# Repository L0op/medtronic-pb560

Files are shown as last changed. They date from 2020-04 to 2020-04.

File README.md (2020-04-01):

# medtronic-pb560
Medtronic PB560 Ventilator System design files. Medtronic distributes these files [here](http://www.medtronic.com/openventilator). The use and distribution of these files is subject to the terms of the license in [permissive-license-open-ventilator.pdf](permissive-license-open-ventilator) ([license on Medtronic's website](https://www.medtronic.com/content/dam/medtronic-com/global/Corporate/covid19/documents/permissive-license-open-ventilator.pdf)). **This license is *not* an [Open-source/Open-hardware license](https://en.wikipedia.org/wiki/Open-source_hardware) in any normal sense.** Specifically:

> _Limited Term._ This permissive license is effective from the time you download the Design Materials and Software until the earlier of (i) the final day the WHO’s PHEIC is in effector  (ii) October 1, 2024 (the “Term”).

Elsewhere:

> **COVID-19 Warning: This Ventilator was created for use onlyin response to the COVID-19 pandemic.  It is provided AS IS.**

The distribution of these materials is solely for the purpose of producing my ventilator.

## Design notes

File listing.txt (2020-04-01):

"."
├── "file-set-1"
│   ├── "Electrical Schematics"
│   │   ├── "10039639C00_Power Supply Board - Tantalum Less_SCH.pdf"
│   │   ├── "10105965B00_10106052_POWERPACK2 BOARD (DUAL BATTERY).pdf"
│   │   ├── "4096600.E00.001_Schma Carte Commande Turbine RB0505 IND03.pdf"
│   │   ├── "4096600.E01.001_Schma Carte Connexion Batterie IND02.pdf"
│   │   ├── "4096600E03001_CPU BOARD SCH.pdf"
│   │   └── "4096600E04001_BUZZER BOARD SCH.pdf"
│   ├── "Manuals"
│   │   ├── "Manual - Service - PB560 - English .pdf"
│   │   └── "Manual - User PB560 - English.pdf"
│   ├── "Manufacturing Documents"
│   │   ├── "PB560 - Quality Process Flow - Manufacturing Procedures"
│   │   │   ├── "10036007Z00_PB560 SYSTEM CALIBRATION AND TEST PROCEDURE.pdf"
│   │   │   ├── "10037308AJ00.pdf"
│   │   │   ├── "10039030M00_PB560 SYSTEM FINAL TEST PROCEDURE.pdf"
│   │   │   ├── "10039897AH00_PB560 PACK.pdf"
│   │   │   ├── "10076002D00_PB500 ELECTRICAL SAFETY TEST AND BUZZER CARD CHARGE PROCEDURE.pdf"
│   │   │   ├── "10095161P00_PB560 ASSEMBLY PROCEDURE 1.pdf"
│   │   │   ├── "10095162H00_PB560 ASSEMBLY PROCEDURE 2.pdf"
│   │   │   └── "10095163H00_PB560 ASSEMBLY PROCEDURE 3.pdf"
│   │   └── "PB560 Power Pack - Quality Process Flow - Manufacturing Procedures"
│   │       ├── "10071204L00 - PB500 Series Power Pack Quality Process Flow.pdf"
│   │       ├── "10099745H00 - PB500 Power Pack Assembly & Test procedure.pdf"
│   │       ├── "10124919G00 - PB500 series Power Pack2 DHR.pdf"
│   │       ├── "10128152J00 - PB500 series POWERPACK 2 pack procedure.pdf"
│   │       └── "10140875D00 - PB500 Powerpack FRU DHR.pdf"
│   ├── "Requirements Documents"
│   │   ├── "10035480AM00 - Product Requirements Document.pdf"
│   │   ├── "10037185AB0 - Software Requirements Specification Document.pdf"
│   │   └── "10053865Q00 - PB560 Ventilator & Power Pack Essential Requirements Matrix.pdf"
│   └── "Permissive License--Open Ventilator.pdf"
├── "file-set-2"
│   ├── "3D CAD Models"
│   │   ├── "039281023.SLDPRT"
│   │   ├── "09-48-4038.SLDPRT"
│   │   ├── "09-48-4128.SLDPRT"
│   │   ├── "10000916.SLDPRT"
│   │   ├── "10049560_Fan Assy (ref ASM).SLDASM"
│   │   ├── "10049560_Routed wires (asm ref Part).SLDPRT"
│   │   ├── "10049560_ventil SUNON 40x40x20.SLDPRT"
│   │   ├── "10079556.SLDASM"
│   │   ├── "10079556_Support.SLDPRT"
│   │   ├── "10083602.SLDPRT"
│   │   ├── "10093284.SLDPRT"
│   │   ├── "10096315.SLDASM"
│   │   ├── "10096505_Board (ref ECAD).SLDPRT"
│   │   ├── "10096509.SLDASM"
│   │   ├── "10096510.sldasm"
│   │   ├── "10096510_Bare Board.SLDPRT"
│   │   ├── "10096511.SLDASM"
│   │   ├── "10096512.SLDASM"
│   │   ├── "10100017.SLDPRT"
│   │   ├── "10100018.SLDPRT"
│   │   ├── "1mm bumper.SLDPRT"
│   │   ├── "2004200 Rondelle plate - MN INOX 3 x 8 EP 0.8.sldprt"
│   │   ├── "22-05-7028.SLDPRT"
│   │   ├── "22-27-2021.SLDPRT"
│   │   ├── "26-48-1035.SLDPRT"
│   │   ├── "26-48-1125.SLDPRT"
│   │   ├── "2961500 Pieds autocollants 12.7x12.7 ep5.8.SLDPRT"
│   │   ├── "2963500 batterie legendair.SLDPRT"
│   │   ├── "2966300 (ref AML).SLDPRT"
│   │   ├── "2970100 goupille cylindrique DIA 2x28.SLDPRT"
│   │   ├── "2970300 raccord droit 2.4x3.2 plastique.SLDPRT"
│   │   ├── "2970400 Raccord TE 2.4 plastique.SLDPRT"
│   │   ├── "2970900 vanne  A-M O2 FAS.SLDPRT"
│   │   ├── "2970999 Vanne  A-M O2 FAS.SLDASM"
│   │   ├── "2973900 (ref AML).SLDPRT"
│   │   ├── "2980100 ferrite 18.8x28.5x13.2.SLDPRT"
│   │   ├── "3808400.SLDASM"
│   │   ├── "3808400_plastic only.SLDPRT"
│   │   ├── "3808801 support cone expiration legendair.SLDPRT"
│   │   ├── "3810200.SLDPRT"
│   │   ├── "3812400 entretoise hexa M-F M3.SLDPRT"
│   │   ├── "3812500 tole blindage toron moteur.SLDPRT"
│   │   ├── "3814200.SLDPRT"
│   │   ├── "3814400 ressort capot.SLDPRT"
│   │   ├── "3822000.SLDPRT"
│   │   ├── "3822500.SLDASM"
│   │   ├── "3822500_WIRES.SLDPRT"
│   │   ├── "3823200.sldasm"
│   │   ├── "3824300 Assy with labels (ref Assy).SLDASM"
│   │   ├── "3824300_Main block.SLDPRT"
│   │   ├── "3824300_Plastic Insert.SLDPRT"
│   │   ├── "3825500.SLDPRT"
│   │   ├── "3827900.SLDPRT"
│   │   ├── "3828200 etiq ident caisson turbine.SLDPRT"
│   │   ├── "3828200.SLDPRT"
│   │   ├── "3828299 REF ASSY (INCLUDES FOAM).SLDASM"
│   │   ├── "3838600 etiq ID+code barre revB.SLDPRT"
│   │   ├── "3838600.SLDPRT"
│   │   ├── "3845900_cable.SLDPRT"
│   │   ├── "3845900_ferrite tube plat 1,3x6,5 prof10 larg 40.SLDPRT"
│   │   ├── "3846100.SLDASM"
│   │   ├── "3846100_Cable.SLDPRT"
│   │   ├── "39-26-7265.SLDPRT"
│   │   ├── "39-28-5104.SLDPRT"
│   │   ├── "39-28-5264.SLDPRT"
│   │   ├── "3M 4032 x30mm.SLDPRT"
│   │   ├── "3M 7810-0000PR.SLDPRT"
│   │   ├── "4096600 (PB560) 2017.SLDASM"
│   │   ├── "4096600.M00.023 boitier capteur debit.SLDPRT"
│   │   ├── "43650-0224.SLDPRT"
│   │   ├── "60601-1 Test Finger.SLDPRT"
│   │   ├── "702-09 Entretoise AV Legendair.SLDPRT"
│   │   ├── "90151-2110.SLDPRT"
│   │   ├── "901700010 avec patte.SLDPRT"
│   │   ├── "90635-1102 +90170-0010 molex avec patte.SLDASM"
│   │   ├── "90635-1102.SLDPRT"
│   │   ├── "AFFICHEUR TWIN.SLDPRT"
│   │   ├── "Back End Cap.SLDPRT"
│   │   ├── "Batt Assy.SLDASM"
│   │   ├── "Batt Contacts tab.SLDPRT"
│   │   ├── "Batt PCB Assy.SLDASM"
│   │   ├── "Batt PCB.SLDPRT"
│   │   ├── "Cable tie (ref AML).SLDPRT"
│   │   ├── "Coude banjo M5-tuyau 6.SLDPRT"
│   │   ├── "Exh Valve connector.SLDPRT"
│   │   ├── "Extruded housing.SLDPRT"
│   │   ├── "Front End Cap.SLDPRT"
│   │   ├── "HARTING 09185107323.SLDPRT"
│   │   ├── "HIROSE HR25A-7R-8S.SLDPRT"
│   │   ├── "HIROSE HR30-6R-6S.SLDPRT"
│   │   ├── "I0 178 Entretoise AR Legendair.SLDPRT"
│   │   ├── "I0 179 Entretoise Mediane Legendair.SLDPRT"
│   │   ├── "INGUN GKS 913 305 230 A 15 02 S.SLDPRT"
│   │   ├── "Insp Mod Connector.SLDPRT"
│   │   ├── "List of 3D CAD files.txt"
│   │   ├── "MODULE PRISE 230+INTER.SLDPRT"
│   │   ├── "MOLEX 22-05-7088.SLDPRT"
│   │   ├── "MOLEX 22-05-7098.SLDPRT"
│   │   ├── "MOLEX 43645 0200.SLDPRT"
│   │   ├── "MOLEX 43650-0212.SLDPRT"
│   │   ├── "Molex 90635-1262.SLDPRT"
│   │   ├── "PMCD1204.sldasm"
│   │   ├── "PRECI-DIP 811-S1-002-30-014101.SLDPRT"
│   │   ├── "Rondelle plate - ZU  3 x 6 EP 0.8.sldprt"
│   │   ├── "Vis KA22x5 hexalobes.SLDPRT"
│   │   ├── "_100800_8.sldprt"
│   │   ├── "_100901_6.sldprt"
│   │   ├── "_PMCD1204_BODY_2.sldprt"
│   │   ├── "_PMC_LATCH_4.sldprt"
│   │   ├── "alimentation phase 2.SLDPRT"
│   │   ├── "alimentation xp.sldasm"
│   │   ├── "boitier capteur pression asdx.SLDPRT"
│   │   ├── "buzzer1.SLDPRT"
│   │   ├── "cache transfo.SLDPRT"
│   │   ├── "capot 2 capteurs P phase 2.SLDPRT"
│   │   ├── "capot 3 capteurs P phase 2.SLDPRT"
│   │   ├── "capteur debit.SLDPRT"
│   │   ├── "capteur pression absolue.SLDPRT"
│   │   ├── "capteurpressionASDX001D44R.SLDPRT"
│   │   ├── "capteurpressionASDX100D44R.SLDPRT"
│   │   ├── "carte buzzer.SLDPRT"
│   │   ├── "carte clairitec.SLDPRT"
│   │   ├── "condensateur C88.SLDPRT"
│   │   ├── "condensateur dia 10.SLDPRT"
│   │   ├── "condensateur.SLDPRT"
│   │   ├── "connect molex 22-01-2025.SLDPRT"
│   │   ├── "connect molex 22-01-2087.SLDPRT"
│   │   ├── "connecteur 12-30V.SLDPRT"
│   │   ├── "connecteur USB A vertical.SLDPRT"
│   │   ├── "connecteur USB miniB.SLDPRT"
│   │   ├── "double face.SLDPRT"
│   │   ├── "embase cpu.SLDPRT"
│   │   ├── "entretoise hexa  m3x12.SLDPRT"
│   │   ├── "entretoise hexa  m3x8.SLDPRT"
│   │   ├── "entretoise richco lg16.SLDPRT"
│   │   ├── "etiq reperage vanne O2.SLDPRT"
│   │   ├── "feritte nappe afficheur.SLDPRT"
│   │   ├── "filtre murata.SLDPRT"
│   │   ├── "new circuit support alimentation avec usb.SLDPRT"
│   │   ├── "regulateur.SLDPRT"
│   │   ├── "self debout.SLDPRT"
│   │   ├── "switch.SLDPRT"
│   │   ├── "thermistances CTN.SLDPRT"
│   │   ├── "transfo.SLDPRT"
│   │   ├── "tuyau  droit sortie vanne O2.SLDPRT"
│   │   ├── "tuyau 15x21 silicone.SLDPRT"
│   │   ├── "tuyau alim ballonnet1.6x4.8.SLDPRT"
│   │   ├── "tuyau alim vanne 1.6x4.8.SLDPRT"
│   │   ├── "tuyau alim vanne 4x6.SLDPRT"
│   │   ├── "tuyau pression interne1.6x4.8.SLDPRT"
│   │   ├── "tuyau pression prox1.6x4.8.SLDPRT"
│   │   ├── "tuyau pression vanne pilot1.6x4.8.SLDPRT"
│   │   ├── "tuyau sortie vanne pilot1.6x4.8.SLDPRT"
│   │   ├── "valve chiprop .SLDPRT"
│   │   └── "valve chiprop.SLDASM"
│   ├── "Electronic PCBAs"
│   │   ├── "10005011_Power Management_PCBA"
│   │   │   ├── "3842800_POWER SUPPLY BOARD - TANTALUM LESS_PCBA"
│   │   │   │   ├── "BOM"
│   │   │   │   │   └── "3842800_POWER SUPPLY BOARD - TANTALUM LESS_BOM.xls"
│   │   │   │   ├── "PCB"
│   │   │   │   │   └── "Power Supply Board 3842800 (Tantalum Less) INDC"
│   │   │   │   │       ├── "CdC Routage Power Supply Board 3842800 (Tantalum less)  INDC.doc"
│   │   │   │   │       ├── "Lisez.xls"
│   │   │   │   │       ├── "det.phd"
│   │   │   │   │       ├── "eqfc.dxf"
│   │   │   │   │       ├── "eqfc.hpg"
│   │   │   │   │       ├── "eqfc.pdf"
│   │   │   │   │       ├── "eqfc.phd"
│   │   │   │   │       ├── "eqfs.dxf"
│   │   │   │   │       ├── "eqfs.hpg"
│   │   │   │   │       ├── "eqfs.pdf"
│   │   │   │   │       ├── "eqfs.phd"
│   │   │   │   │       ├── "f2.phd"
│   │   │   │   │       ├── "f3.phd"
│   │   │   │   │       ├── "f4.phd"
│   │   │   │   │       ├── "f5.phd"
│   │   │   │   │       ├── "fc.phd"
│   │   │   │   │       ├── "fs.phd"
│   │   │   │   │       ├── "net.ccf"
│   │   │   │   │       ├── "pabc.phd"
│   │   │   │   │       ├── "pabs.phd"
│   │   │   │   │       ├── "partslist.rep"
│   │   │   │   │       ├── "per.dxf"
│   │   │   │   │       ├── "per.hpg"
│   │   │   │   │       ├── "per.pdf"
│   │   │   │   │       ├── "per0.drd"
│   │   │   │   │       ├── "per0.drl"
│   │   │   │   │       ├── "per1.drd"
│   │   │   │   │       ├── "per1.drl"
│   │   │   │   │       ├── "powersupply-c.brd"
│   │   │   │   │       ├── "powersupply-c.ftf"
│   │   │   │   │       ├── "powersupply-c.pcf"
│   │   │   │   │       ├── "powersupply-c.pro"
│   │   │   │   │       ├── "sefc.pdf"
│   │   │   │   │       ├── "sefc.phd"
│   │   │   │   │       ├── "sefs.pdf"
│   │   │   │   │       ├── "sefs.phd"
│   │   │   │   │       ├── "vec.phd"
│   │   │   │   │       └── "ves.phd"
│   │   │   │   ├── "PCBA"
│   │   │   │   │   ├── "09-48-4038.SLDPRT"
│   │   │   │   │   ├── "09-48-4128.SLDPRT"
│   │   │   │   │   ├── "22-27-2021.SLDPRT"
│   │   │   │   │   ├── "26-48-1035.SLDPRT"
│   │   │   │   │   ├── "26-48-1125.SLDPRT"
│   │   │   │   │   ├── "3842800 carte gestion des alimentations PB 560.sldasm"
│   │   │   │   │   ├── "3842800F00.SLDDRW"
│   │   │   │   │   ├── "3842800F00.pdf"
│   │   │   │   │   ├── "39-26-7265.SLDPRT"
│   │   │   │   │   ├── "43650-0224.SLDPRT"
│   │   │   │   │   ├── "90151-2110.SLDPRT"
│   │   │   │   │   ├── "MODULE PRISE 230+INTER.SLDPRT"
│   │   │   │   │   ├── "alimentation phase 2.SLDPRT"
│   │   │   │   │   ├── "alimentation xp.sldasm"
│   │   │   │   │   ├── "condensateur dia 10.SLDPRT"
│   │   │   │   │   ├── "connecteur 12-30V.SLDPRT"
│   │   │   │   │   ├── "connecteur USB A vertical.SLDPRT"
│   │   │   │   │   ├── "connecteur USB miniB.SLDPRT"
│   │   │   │   │   ├── "entretoise hexa  m3x12.SLDPRT"
│   │   │   │   │   ├── "entretoise richco lg16.SLDPRT"
│   │   │   │   │   ├── "filtre murata.SLDPRT"
│   │   │   │   │   ├── "new circuit support alimentation avec usb.SLDPRT"
│   │   │   │   │   ├── "self debout.SLDPRT"
│   │   │   │   │   └── "thermistances CTN.SLDPRT"
│   │   │   │   └── "SCH"
│   │   │   │       └── "10039639C00_Power Supply Board - Tantalum Less_SCH.pdf"
│   │   │   └── "10025029E00_POWER BOARD REQUIREMENTS SPECIFICATION, PB 540 .doc"
│   │   ├── "10096315_Blower_Driver_PCBA"
│   │   │   ├── "3D_Model"
│   │   │   │   ├── "039281023.SLDPRT"
│   │   │   │   ├── "10096315.SLDDRW"
│   │   │   │   ├── "22-05-7028.SLDPRT"
│   │   │   │   ├── "22-05-7088.SLDPRT"
│   │   │   │   ├── "22-05-7098.SLDPRT"
│   │   │   │   ├── "3838600 etiq ID+code barre revB.SLDPRT"
│   │   │   │   ├── "3838600A00.SLDPRT"
│   │   │   │   ├── "3845700 carte cde turbine PB560.SLDASM"
│   │   │   │   ├── "3845701 cable nappe alim 10 brins.SLDASM"
│   │   │   │   ├── "43650-0212.SLDPRT"
│   │   │   │   ├── "7810-0000xxSE.SLDPRT"
│   │   │   │   ├── "901700010 avec patte.SLDPRT"
│   │   │   │   ├── "90635-1102 +90170-0010 molex avec patte.SLDASM"
│   │   │   │   ├── "90635-1102.SLDPRT"
│   │   │   │   ├── "cable nappe 10 fils.SLDPRT"
│   │   │   │   └── "regulateur.SLDPRT"
│   │   │   ├── "BOM"
│   │   │   │   └── "10096315_Blower_Driver_PCBA_BOM.xls"
│   │   │   ├── "PCB"
│   │   │   │   ├── "10096505A00"
│   │   │   │   │   ├── "Lisez.xls"
│   │   │   │   │   ├── "ctrb0505-A.brd"
│   │   │   │   │   ├── "ctrb0505-A.ftf"
│   │   │   │   │   ├── "ctrb0505-A.pcf"
│   │   │   │   │   ├── "ctrb0505-A.pro"
│   │   │   │   │   ├── "det.phd"
│   │   │   │   │   ├── "eqfc.dxf"
│   │   │   │   │   ├── "eqfc.hpg"
│   │   │   │   │   ├── "eqfc.pdf"
│   │   │   │   │   ├── "eqfc.phd"
│   │   │   │   │   ├── "eqfs.dxf"
│   │   │   │   │   ├── "eqfs.hpg"
│   │   │   │   │   ├── "eqfs.pdf"
│   │   │   │   │   ├── "eqfs.phd"
│   │   │   │   │   ├── "f2.phd"
│   │   │   │   │   ├── "f3.phd"
│   │   │   │   │   ├── "fc.phd"
│   │   │   │   │   ├── "fs.phd"
│   │   │   │   │   ├── "pabc.phd"
│   │   │   │   │   ├── "pabs.phd"
│   │   │   │   │   ├── "partslist.doc"
│   │   │   │   │   ├── "per.dxf"
│   │   │   │   │   ├── "per.hpg"
│   │   │   │   │   ├── "per.pdf"
│   │   │   │   │   ├── "per0.drd"
│   │   │   │   │   ├── "per0.drl"
│   │   │   │   │   ├── "sefc.pdf"
│   │   │   │   │   ├── "sefc.phd"
│   │   │   │   │   ├── "sefs.pdf"
│   │   │   │   │   ├── "sefs.phd"
│   │   │   │   │   ├── "vec.phd"
│   │   │   │   │   └── "ves.phd"
│   │   │   │   └── "10096505A00.pdf"
│   │   │   ├── "PCBA"
│   │   │   │   └── "10096315A00.PDF"
│   │   │   ├── "SCH"
│   │   │   │   └── "4096600.E00.001_Schma Carte Commande Turbine RB0505 IND03.pdf"
│   │   │   ├── "10024947D00_TURBINE CONTROL BOARD REQUIREMENTS SPECIFICATION, PB 540 .doc"
│   │   │   └── "10025027E00_TURBINE BOX HARDWARE SPECIFICATION, PB 540.doc"
│   │   ├── "10096510_Battery_Connection_PCBA"
│   │   │   ├── "3D_Model"
│   │   │   │   ├── "10096510.SLDDRW"
│   │   │   │   ├── "3821203 carte connexion batterie.sldasm"
│   │   │   │   ├── "39-26-7108.SLDPRT"
│   │   │   │   ├── "connecteur batterie.SLDPRT"
│   │   │   │   └── "contact ressort.SLDPRT"
│   │   │   ├── "BOM"
│   │   │   │   └── "10096510_Battery_Connection_PCBA_BOM.xls"
│   │   │   ├── "PCB"
│   │   │   │   ├── "10096506A00"
│   │   │   │   │   ├── "Lisez.xls"
│   │   │   │   │   ├── "cbr0505-A.brd"
│   │   │   │   │   ├── "cbr0505-A.ftf"
│   │   │   │   │   ├── "cbr0505-A.pcf"
│   │   │   │   │   ├── "cbr0505-A.pro"
│   │   │   │   │   ├── "det.phd"
│   │   │   │   │   ├── "eqfc.dxf"
│   │   │   │   │   ├── "eqfc.hpg"
│   │   │   │   │   ├── "eqfc.pdf"
│   │   │   │   │   ├── "eqfc.phd"
│   │   │   │   │   ├── "eqfs.dxf"
│   │   │   │   │   ├── "eqfs.hpg"
│   │   │   │   │   ├── "eqfs.pdf"
│   │   │   │   │   ├── "eqfs.phd"
│   │   │   │   │   ├── "fc.phd"
│   │   │   │   │   ├── "fs.phd"
│   │   │   │   │   ├── "pabc.phd"
│   │   │   │   │   ├── "pabs.phd"
│   │   │   │   │   ├── "partslist.doc"
│   │   │   │   │   ├── "per.dxf"
│   │   │   │   │   ├── "per.hpg"
│   │   │   │   │   ├── "per.pdf"
│   │   │   │   │   ├── "per0.drd"
│   │   │   │   │   ├── "per0.drl"
│   │   │   │   │   ├── "per1.drd"
│   │   │   │   │   ├── "per1.drl"
│   │   │   │   │   ├── "sefc.pdf"
│   │   │   │   │   ├── "sefc.phd"
│   │   │   │   │   ├── "sefs.pdf"
│   │   │   │   │   ├── "sefs.phd"
│   │   │   │   │   ├── "vec.phd"
│   │   │   │   │   └── "ves.phd"
│   │   │   │   └── "10096506A00.pdf"
│   │   │   ├── "PCBA"
│   │   │   │   └── "10096510A00.PDF"
│   │   │   └── "10024249C00_BATTERY CONNECTION BOARD, US, PB 540 SPECIFICATION .doc"
│   │   ├── "10106052_PowerPack_PCBA"
│   │   │   ├── "3D_Model"
│   │   │   │   ├── "10106054.SLDDRW"
│   │   │   │   └── "10106054A00.PDF"
│   │   │   ├── "BOM"
│   │   │   │   └── "10106052_POWERPACK2 BOARD (DUAL BATTERY)_BOM.xls"
│   │   │   ├── "PCB"
│   │   │   │   ├── "10106054A00.pcb"
│   │   │   │   ├── "10106054A00.tgz"
│   │   │   │   └── "10107738A00.pdf"
│   │   │   ├── "PCBA"
│   │   │   │   ├── "10106052.SLDASM"
│   │   │   │   ├── "10106052.SLDDRW"
│   │   │   │   ├── "10106052C00.PDF"
│   │   │   │   ├── "10106052_Batt GND Contact.SLDPRT"
│   │   │   │   ├── "10106052_Batt contact 2pin pogo.SLDPRT"
│   │   │   │   ├── "10106052_EMI Suppressor.sldprt"
│   │   │   │   ├── "10106052_Relay.SLDPRT"
│   │   │   │   ├── "10106054.SLDPRT"
│   │   │   │   ├── "3838600 REF.SLDPRT"
│   │   │   │   ├── "5220719601.sldprt"
│   │   │   │   ├── "5220719602.sldprt"
│   │   │   │   ├── "5220719603.sldprt"
│   │   │   │   ├── "JST S2B-ZR-SM4A-TF.SLDPRT"
│   │   │   │   ├── "MOLEX 02661-4020.SLDPRT"
│   │   │   │   ├── "MOLEX 43650-0229.SLDPRT"
│   │   │   │   └── "MOLEX 52207-1960.SLDASM"
│   │   │   ├── "SCH"
│   │   │   │   ├── "10105965B00.DSN"
│   │   │   │   └── "10105965B00.pdf"
│   │   │   └── "10025023G00_BATTERY HARDWARE SPECIFICATION, PB560 PB540 PB520 .doc"
│   │   ├── "GR106768_Buzzer_PCBA"
│   │   │   ├── "3D_Model"
│   │   │   │   ├── "3836700 carte buzzer RB0505.SLDASM"
│   │   │   │   ├── "3838600 etiq ID+code barre revB.SLDPRT"
│   │   │   │   ├── "GR106768.slddrw"
│   │   │   │   ├── "buzzer1.SLDPRT"
│   │   │   │   ├── "cache transfo.SLDPRT"
│   │   │   │   ├── "carte buzzer.SLDPRT"
│   │   │   │   ├── "condensateur.SLDPRT"
│   │   │   │   ├── "switch.SLDPRT"
│   │   │   │   └── "transfo.SLDPRT"
│   │   │   ├── "BOM"
│   │   │   │   └── "GR106768_Buzzer_PCBA_BOM.xls"
│   │   │   ├── "PCB"
│   │   │   │   ├── "GR106771 Rev A.pdf"
│   │   │   │   ├── "GR106771-A-ASB-eqfs.phd"
│   │   │   │   ├── "GR106771-A-AST-eqfc.phd"
│   │   │   │   ├── "GR106771-A-CL2-f2.phd"
│   │   │   │   ├── "GR106771-A-CL3-f3.phd"
│   │   │   │   ├── "GR106771-A-CLB-fs.phd"
│   │   │   │   ├── "GR106771-A-CLT-fc.phd"
│   │   │   │   ├── "GR106771-A-OUT-det.phd"
│   │   │   │   ├── "GR106771-A-PTH-per0.drd"
│   │   │   │   ├── "GR106771-A-PTH-per0.drl"
│   │   │   │   ├── "GR106771-A-SMB-ves.phd"
│   │   │   │   ├── "GR106771-A-SMT-vec.phd"
│   │   │   │   ├── "GR106771-A-SPT-pabc.phd"
│   │   │   │   ├── "GR106771-A-SSB-sefs.PDF"
│   │   │   │   ├── "GR106771-A-SSB-sefs.phd"
│   │   │   │   ├── "GR106771-A-SST-sefc.PDF"
│   │   │   │   ├── "GR106771-A-SST-sefc.phd"
│   │   │   │   ├── "GR106771-A-partslist.doc"
│   │   │   │   ├── "GR106771-A.brd"
│   │   │   │   ├── "GR106771-A.ftf"
│   │   │   │   ├── "GR106771-A.pcf"
│   │   │   │   ├── "GR106771-A.pro"
│   │   │   │   ├── "GR106771-PEQ-A_Bottom.dxf"
│   │   │   │   ├── "GR106771-PEQ-A_Bottom.hpg"
│   │   │   │   ├── "GR106771-PEQ-A_Bottom.pdf"
│   │   │   │   ├── "GR106771-PEQ-A_Top.dxf"
│   │   │   │   ├── "GR106771-PEQ-A_Top.hpg"
│   │   │   │   ├── "GR106771-PEQ-A_Top.pdf"
│   │   │   │   ├── "GR106771-PPD-A.dxf"
│   │   │   │   ├── "GR106771-PPD-A.hpg"
│   │   │   │   ├── "GR106771-PPD-A.pdf"
│   │   │   │   ├── "GR106771.slddrw"
│   │   │   │   ├── "GR106771A00.pdf"
│   │   │   │   ├── "GR106771_REV_A.NET"
│   │   │   │   └── "Read-me.xls"
│   │   │   ├── "PCBA"
│   │   │   │   ├── "3836700 carte buzzer RB0505.SLDASM"
│   │   │   │   ├── "3838600 etiq ID+code barre revB.SLDPRT"
│   │   │   │   ├── "GR106768.slddrw"
│   │   │   │   ├── "GR106768B00.pdf"
│   │   │   │   ├── "buzzer1.SLDPRT"
│   │   │   │   ├── "cache transfo.SLDPRT"
│   │   │   │   ├── "carte buzzer.SLDPRT"
│   │   │   │   ├── "condensateur.SLDPRT"
│   │   │   │   ├── "switch.SLDPRT"
│   │   │   │   └── "transfo.SLDPRT"
│   │   │   ├── "SCH"
│   │   │   │   ├── "10125624A00.pdf"
│   │   │   │   └── "10125624A00.sch"
│   │   │   └── "10025028E00_BUZZER BOARD REQUIREMENTS SPECIFICATION, PB500 SERIES.doc"
│   │   └── "GR106769_CPU_PCBA"
│   │       ├── "3D_Model"
│   │       │   ├── "2004200 Rondelle plate - MN INOX 3 x 8 EP 0.8.sldprt"
│   │       │   ├── "22-05-7028.SLDPRT"
│   │       │   ├── "3821300 carte cpu RB0505.SLDASM"
│   │       │   ├── "3838600.SLDPRT"
│   │       │   ├── "39-28-5104.SLDPRT"
│   │       │   ├── "39-28-5264.SLDPRT"
│   │       │   ├── "4096600.M00.023 boitier capteur debit.SLDPRT"
│   │       │   ├── "AFFICHEUR TWIN.SLDPRT"
│   │       │   ├── "GR106769.SLDDRW"
│   │       │   ├── "Rondelle plate - ZU  3 x 6 EP 0.8.sldprt"
│   │       │   ├── "Vis KA22x5 hexalobes.SLDPRT"
│   │       │   ├── "boitier capteur pression asdx.SLDPRT"
│   │       │   ├── "capot 2 capteurs P phase 2.SLDPRT"
│   │       │   ├── "capot 3 capteurs P phase 2.SLDPRT"
│   │       │   ├── "capteur debit.SLDPRT"
│   │       │   ├── "capteur pression absolue.SLDPRT"
│   │       │   ├── "capteurpressionASDX001D44R.SLDPRT"
│   │       │   ├── "capteurpressionASDX100D44R.SLDPRT"
│   │       │   ├── "carte clairitec.SLDPRT"
│   │       │   ├── "condensateur C88.SLDPRT"
│   │       │   ├── "connector.SLDPRT"
│   │       │   ├── "double face.SLDPRT"
│   │       │   ├── "embase cpu.SLDPRT"
│   │       │   ├── "entretoise hexa  m3x12.SLDPRT"
│   │       │   ├── "entretoise hexa  m3x8.SLDPRT"
│   │       │   ├── "feritte nappe afficheur.SLDPRT"
│   │       │   ├── "valve chiprop .SLDPRT"
│   │       │   └── "valve chiprop.SLDASM"
│   │       ├── "BOM"
│   │       │   └── "GR106769_CPU_PCBA_BOM.xls"
│   │       ├── "PCB"
│   │       │   ├── "GR106772 Rev A.PDF.pdf"
│   │       │   ├── "GR106772-A-ASB-eqfs.phd"
│   │       │   ├── "GR106772-A-AST-eqfc.phd"
│   │       │   ├── "GR106772-A-CL2-f2.phd"
│   │       │   ├── "GR106772-A-CL3-f3.phd"
│   │       │   ├── "GR106772-A-CL4-f4.phd"
│   │       │   ├── "GR106772-A-CL5-f5.phd"
│   │       │   ├── "GR106772-A-CLB-fs.phd"
│   │       │   ├── "GR106772-A-CLT-fc.phd"
│   │       │   ├── "GR106772-A-NPTH-per1.drd"
│   │       │   ├── "GR106772-A-NPTH-per1.drl"
│   │       │   ├── "GR106772-A-OUT-det.phd"
│   │       │   ├── "GR106772-A-PTH-per0.drd"
│   │       │   ├── "GR106772-A-PTH-per0.drl"
│   │       │   ├── "GR106772-A-SMB-ves.phd"
│   │       │   ├── "GR106772-A-SMT-vec.phd"
│   │       │   ├── "GR106772-A-SPB-pabs.phd"
│   │       │   ├── "GR106772-A-SPT-pabc.phd"
│   │       │   ├── "GR106772-A-SSB-sefs.pdf"
│   │       │   ├── "GR106772-A-SSB-sefs.phd"
│   │       │   ├── "GR106772-A-SST-sefc.pdf"
│   │       │   ├── "GR106772-A-SST-sefc.phd"
│   │       │   ├── "GR106772-A-partslist.doc"
│   │       │   ├── "GR106772-A.brd"
│   │       │   ├── "GR106772-A.ftf"
│   │       │   ├── "GR106772-A.pcf"
│   │       │   ├── "GR106772-A.pro"
│   │       │   ├── "GR106772-PEQ-A_Bottom.dxf"
│   │       │   ├── "GR106772-PEQ-A_Bottom.hpg"
│   │       │   ├── "GR106772-PEQ-A_Bottom.pdf"
│   │       │   ├── "GR106772-PEQ-A_Top.PDF"
│   │       │   ├── "GR106772-PEQ-A_Top.dxf"
│   │       │   ├── "GR106772-PEQ-A_Top.hpg"
│   │       │   ├── "GR106772-PPD-A.PDF"
│   │       │   ├── "GR106772-PPD-A.dxf"
│   │       │   ├── "GR106772-PPD-A.hpg"
│   │       │   ├── "GR106772.slddrw"
│   │       │   ├── "GR106772A00.pdf"
│   │       │   ├── "GR106772_REV_A.NET"
│   │       │   └── "Read-me.xls"
│   │       ├── "PCBA"
│   │       │   └── "GR106769B00.pdf"
│   │       ├── "SCH"
│   │       │   ├── "10125623A00.pdf"
│   │       │   └── "10125623A00.sch"
│   │       ├── "10024980G00_CPU BOARD REQUIREMENTS SPECIFICATION, PB 540 .doc"
│   │       ├── "10025024C00_EXHALATION CONTROL VALVE HARDWARE SPECIFICATION, PB 540.doc"
│   │       ├── "10025025B00_OXYGEN VALVE HARDWARE SPECIFICATION, PB 540 .doc"
│   │       ├── "10025026C00_RELIEF VALVE HARDWARE SPECIFICATION, PB 540.doc"
│   │       └── "3832100F00_SOFTWARE REFERENCE DRAWING PB540 POWER SUPPLY.doc"
│   ├── "Manufacturing Fixtures"
│   │   ├── "10021741_A - Stopcock, 1 way.pdf"
│   │   ├── "10021741_A.dwg"
│   │   ├── "10021744 Approved  Revision  A.dwg"
│   │   ├── "10021744 Approved  Revision  A.pdf"
│   │   ├── "10021745D00.pdf"
│   │   ├── "10022189 Approved Revision A.pdf"
│   │   ├── "10022190B00.pdf"
│   │   ├── "10025172 A00 PLASTIC TUBE CUTTER 6.4MM.pdf"
│   │   ├── "10025172 A00.dwg"
│   │   ├── "10025203A00.pdf"
│   │   ├── "10025244B00.pdf"
│   │   ├── "10025245A00.pdf"
│   │   ├── "10029105A00.pdf"
│   │   ├── "10031632A00.pdf"
│   │   ├── "3834500 Approved Revision 01.pdf"
│   │   ├── "3835000 Approved Revision 00.pdf"
│   │   ├── "3835100 Approved Revision 00.pdf"
│   │   └── "PT00057819A00 Fixture, PB500 FRU Battery Assembly Aid.pdf"
│   ├── "Mechanical Part Drawings"
│   │   ├── "016294_RMS1"
│   │   │   └── "016294X0301.pdf"
│   │   ├── "10000915"
│   │   │   ├── "10000915.SLDDRW"
│   │   │   ├── "10000915.SLDPRT"
│   │   │   └── "10000915B00.PDF"
│   │   ├── "10004932"
│   │   │   ├── "10000916.SLDPRT"
│   │   │   ├── "10004932.SLDDRW"
│   │   │   └── "10004932C00.PDF"
│   │   ├── "10025112"
│   │   │   ├── "Datasheet - S142.0048a.pdf"
│   │   │   └── "Drawing - S1420048a.pdf"
│   │   ├── "10047943"
│   │   │   ├── "10047943A01.dwg"
│   │   │   ├── "10047943A01.pdf"
│   │   │   ├── "10047943A01_2.dwg"
│   │   │   ├── "10047943A02.dwg"
│   │   │   ├── "10047943A02.pdf"
│   │   │   ├── "10047943A02_2.dwg"
│   │   │   ├── "10047943A03.dwg"
│   │   │   ├── "10047943A03.pdf"
│   │   │   ├── "10047943A03_2.dwg"
│   │   │   ├── "10047943A04.dwg"
│   │   │   ├── "10047943A04.pdf"
│   │   │   ├── "10047943A04_2.dwg"
│   │   │   ├── "10047943A05.dwg"
│   │   │   ├── "10047943A05.pdf"
│   │   │   ├── "10047943A05_2.dwg"
│   │   │   └── "10047943A05_3.dwg"
│   │   ├── "10049560"
│   │   │   ├── "10049560.SLDDRW"
│   │   │   ├── "10049560D00.PDF"
│   │   │   └── "10049560_ventil SUNON 40x40x20.SLDPRT"
│   │   ├── "10053480"
│   │   │   ├── "10053480B01.dwg"
│   │   │   └── "10053480B01.pdf"
│   │   ├── "10079556"
│   │   │   ├── "10079556.SLDASM"
│   │   │   ├── "10079556.SLDDRW"
│   │   │   ├── "10079556B00.PDF"
│   │   │   ├── "10079556_Support.SLDPRT"
│   │   │   ├── "Insp Mod Connector.SLDPRT"
│   │   │   └── "Insp Mod Wire Mesh.SLDPRT"
│   │   ├── "10080310"
│   │   │   ├── "10080310E00.dwg"
│   │   │   └── "10080310E00.pdf"
│   │   ├── "2963300"
│   │   │   ├── "2963300.SLDDRW"
│   │   │   └── "2963300B00.PDF"
│   │   ├── "2967200"
│   │   │   ├── "2967200.SLDASM"
│   │   │   ├── "2967200.SLDDRW"
│   │   │   ├── "2967200C00.pdf"
│   │   │   ├── "2967200_IPX Label.sldprt"
│   │   │   ├── "2967200_Main Bag Label.sldprt"
│   │   │   ├── "Assemblage suspente.SLDASM"
│   │   │   ├── "Assemblage2^sangle droite.sldasm"
│   │   │   ├── "Assemblage3^sangle gauche.sldasm"
│   │   │   ├── "ceinturage.SLDPRT"
│   │   │   ├── "mousqueton.SLDPRT"
│   │   │   ├── "peau exterieure phase 2.SLDPRT"
│   │   │   ├── "sacoche sacar.SLDASM"
│   │   │   ├── "sangle bandoulliere droite.SLDPRT"
│   │   │   ├── "sangle droite.SLDASM"
│   │   │   └── "suspente.SLDPRT"
│   │   ├── "2970900"
│   │   │   ├── "2970900.SLDDRW"
│   │   │   ├── "2970900A00.PDF"
│   │   │   └── "S0122148g (2).pdf"
│   │   ├── "2971700"
│   │   │   ├── "2971700.SLDDRW"
│   │   │   ├── "2971700B00.pdf"
│   │   │   ├── "2971700C00.PDF"
│   │   │   ├── "EGB-rev4-.jpg"
│   │   │   └── "EGB-rev4-.pdf"
│   │   ├── "2982400"
│   │   │   ├── "72SP - Supporting Documentation"
│   │   │   │   ├── "1400-10010_SCH-LegendSchematicV4.3.PDF"
│   │   │   │   ├── "L6A051BE00004 (2982400)_Issue K.pdf"
│   │   │   │   ├── "L6A051BE00004_BOM_Issue K.pdf"
│   │   │   │   ├── "L6A051BE00004_FC_(2982400)_Issue J.pdf"
│   │   │   │   ├── "L6A051BE00004_WI_Issue C_Stage 1.pdf"
│   │   │   │   ├── "L6A051BE00004_WI_Issue C_Stage 2.pdf"
│   │   │   │   ├── "L6A051BE00004_WI_Issue C_Stage 3.pdf"
│   │   │   │   ├── "L6A051BE00004_WI_Issue C_Stage 4.pdf"
│   │   │   │   ├── "L6A051BE00004_WI_Issue C_Stage 5.pdf"
│   │   │   │   ├── "PCBA10003A01G  Control Document v1.1.pdf"
│   │   │   │   ├── "PCBA10003A01G-LegendG2BOMv1.0.pdf"
│   │   │   │   └── "TLS06F006-C Covidien PB540 PB560 Spec 2982400 Rev 2_7.pdf"
│   │   │   ├── "2982400.SLDDRW"
│   │   │   ├── "2982400F00.pdf"
│   │   │   ├── "Battery Drawing.SLDPRT"
│   │   │   └── "ICR18650J.pdf"
│   │   ├── "3809700"
│   │   │   ├── "3809700.SLDDRW"
│   │   │   └── "3809700A00.PDF"
│   │   ├── "3810200"
│   │   │   ├── "3810200.SLDDRW"
│   │   │   ├── "38102000300.pdf"
│   │   │   ├── "3810200A00.PDF"
│   │   │   └── "3810200_Approved_Revision_03.pdf"
│   │   ├── "3812500"
│   │   │   ├── "3812500 tole blindage toron moteur.SLDPRT"
│   │   │   ├── "3812500.SLDDRW"
│   │   │   ├── "3812500A00 .PDF"
│   │   │   └── "4095700.SLDASM"
│   │   ├── "3814200"
│   │   │   ├── "3814200 capot interrupteur.SLDPRT"
│   │   │   ├── "3814200A00.PDF"
│   │   │   └── "3814200A00.SLDDRW"
│   │   ├── "3822800"
│   │   │   ├── "3822800 accroche cable 6.6x4.3.SLDPRT"
│   │   │   ├── "3822800.SLDDRW"
│   │   │   └── "3822800A00.PDF"
│   │   ├── "3822900"
│   │   │   ├── "3822900 .SLDDRW"
│   │   │   ├── "3822900 clip accroche cable 6.6x4.3.SLDPRT"
│   │   │   ├── "3822900A00.PDF"
│   │   │   └── "serre cable 03 japon.SLDASM"
│   │   ├── "3823200"
│   │   │   ├── "3823200.SLDDRW"
│   │   │   └── "3823200B00.PDF"
│   │   ├── "3823600"
│   │   │   ├── "3808407 Coque sup + entretoises.SLDASM"
│   │   │   ├── "3808407 coque sup legendair.SLDPRT"
│   │   │   ├── "3823600.SLDDRW"
│   │   │   ├── "3823600C00.PDF"
│   │   │   ├── "702-09 Entretoise AV Legendair.SLDPRT"
│   │   │   ├── "I0 178 Entretoise AR Legendair.SLDPRT"
│   │   │   └── "I0 179 Entretoise Mediane Legendair.SLDPRT"
│   │   ├── "3823900"
│   │   │   ├── "3822000 couvercle batterie RB 0505.SLDPRT"
│   │   │   ├── "3823900.SLDDRW"
│   │   │   └── "3823900C00.PDF"
│   │   ├── "3824200"
│   │   │   ├── "3808800 support cone expiration legendair NC.SLDDRW"
│   │   │   ├── "3808800 support cone expiration legendair rev A.SLDDRW"
│   │   │   ├── "3808801 support cone expiration legendair.SLDDRW"
│   │   │   ├── "3808801 support cone expiration legendair.SLDPRT"
│   │   │   ├── "3824200.SLDDRW"
│   │   │   └── "3824200B00.PDF"
│   │   ├── "3824300"
│   │   │   ├── "10064411A00.pdf"
│   │   │   ├── "3824300.SLDDRW"
│   │   │   ├── "3824300B00.PDF"
│   │   │   └── "insert M4 Type TH ''SERPLAST''.sldprt"
│   │   ├── "3825500"
│   │   │   ├── "3825500.SLDPRT"
│   │   │   ├── "3825500.slddrw"
│   │   │   └── "3825500E00.PDF"
│   │   ├── "3827900"
│   │   │   ├── "3827900 equerre support vanne O2.SLDPRT"
│   │   │   ├── "3827900.SLDDRW"
│   │   │   └── "3827900B00.PDF"
│   │   ├── "3829000"
│   │   │   ├── "3829000 sacoche transport.SLDPRT"
│   │   │   ├── "3829000.SLDASM"
│   │   │   ├── "3829000.SLDDRW"
│   │   │   ├── "3829000C00.PDF"
│   │   │   ├── "3829000C00.xls"
│   │   │   ├── "Assemblage suspente.SLDASM"
│   │   │   ├── "accroche sangle 25.SLDPRT"
│   │   │   ├── "mica transparent.SLDPRT"
│   │   │   ├── "mousqueton.SLDPRT"
│   │   │   ├── "suspente.SLDPRT"
│   │   │   └── "toile dessus.SLDPRT"
│   │   ├── "4-007303-00"
│   │   │   └── "4-007303-00F00.pdf"
│   │   ├── "4-076684-00"
│   │   │   └── "4-076684-00.pdf"
│   │   ├── "5077700"
│   │   │   └── "5077700 T CONNECTION 22M22F.doc"
│   │   └── "5094000"
│   │       ├── "5094000N00.dwg"
│   │       └── "5094000N00.pdf"
│   ├── "Permissive License--Open Ventilator.pdf"
│   └── "listing.txt"
├── "listing.txt"
├── "medtronic-pb560-ventilator-system-file-set-1.zip"
├── "medtronic-pb560-ventilator-system-file-set-2.zip"
└── "permissive-license-open-ventilator.pdf"

83 directories, 667 files

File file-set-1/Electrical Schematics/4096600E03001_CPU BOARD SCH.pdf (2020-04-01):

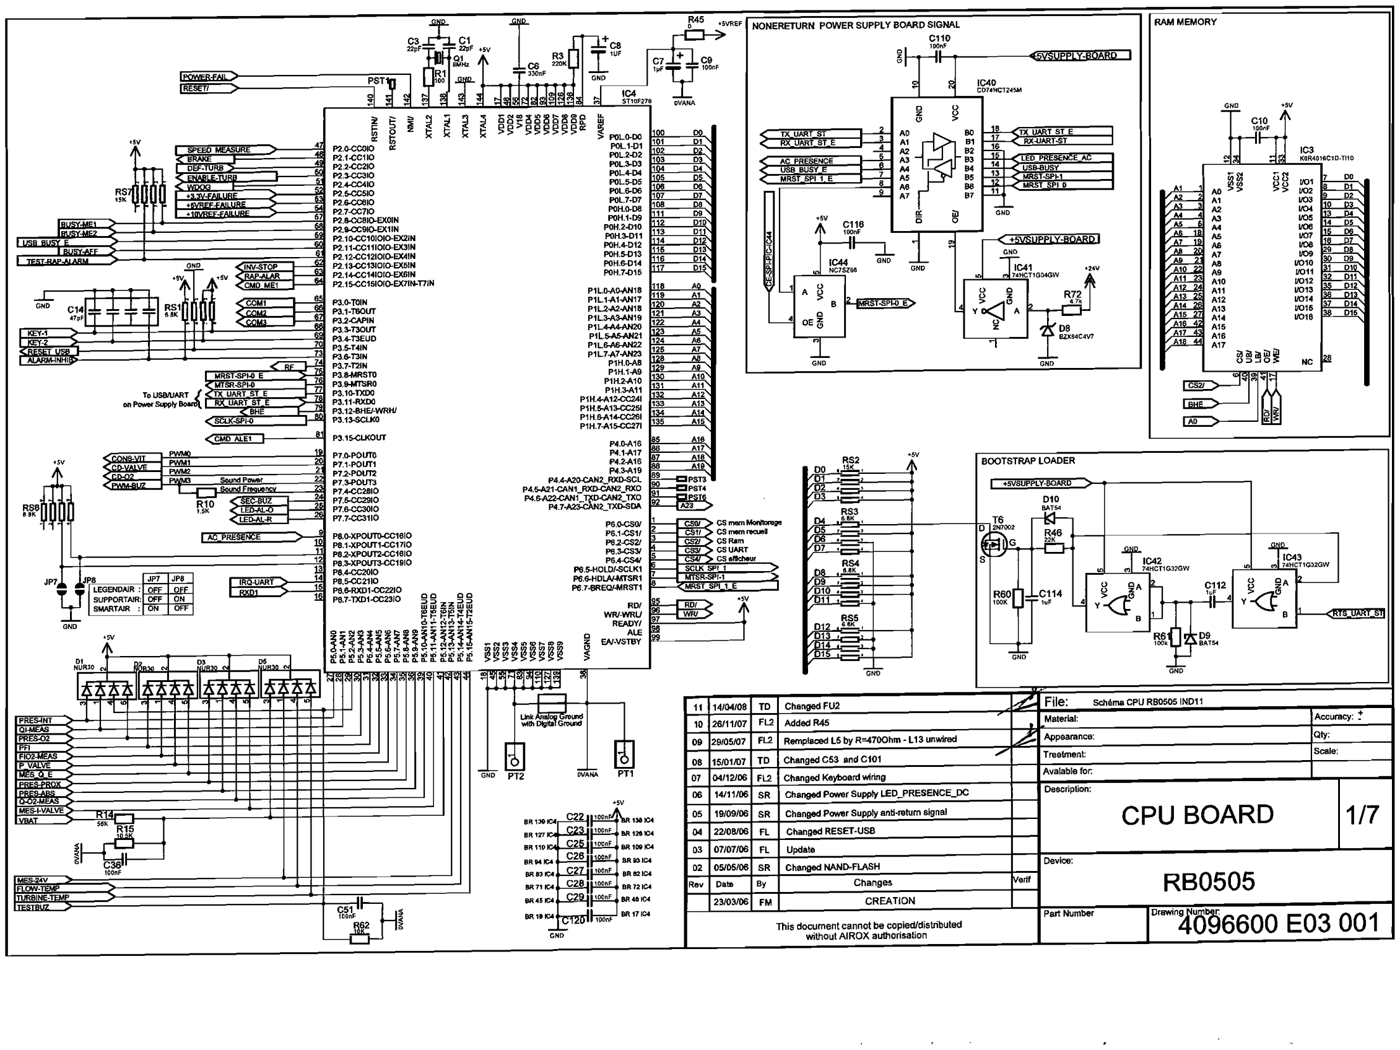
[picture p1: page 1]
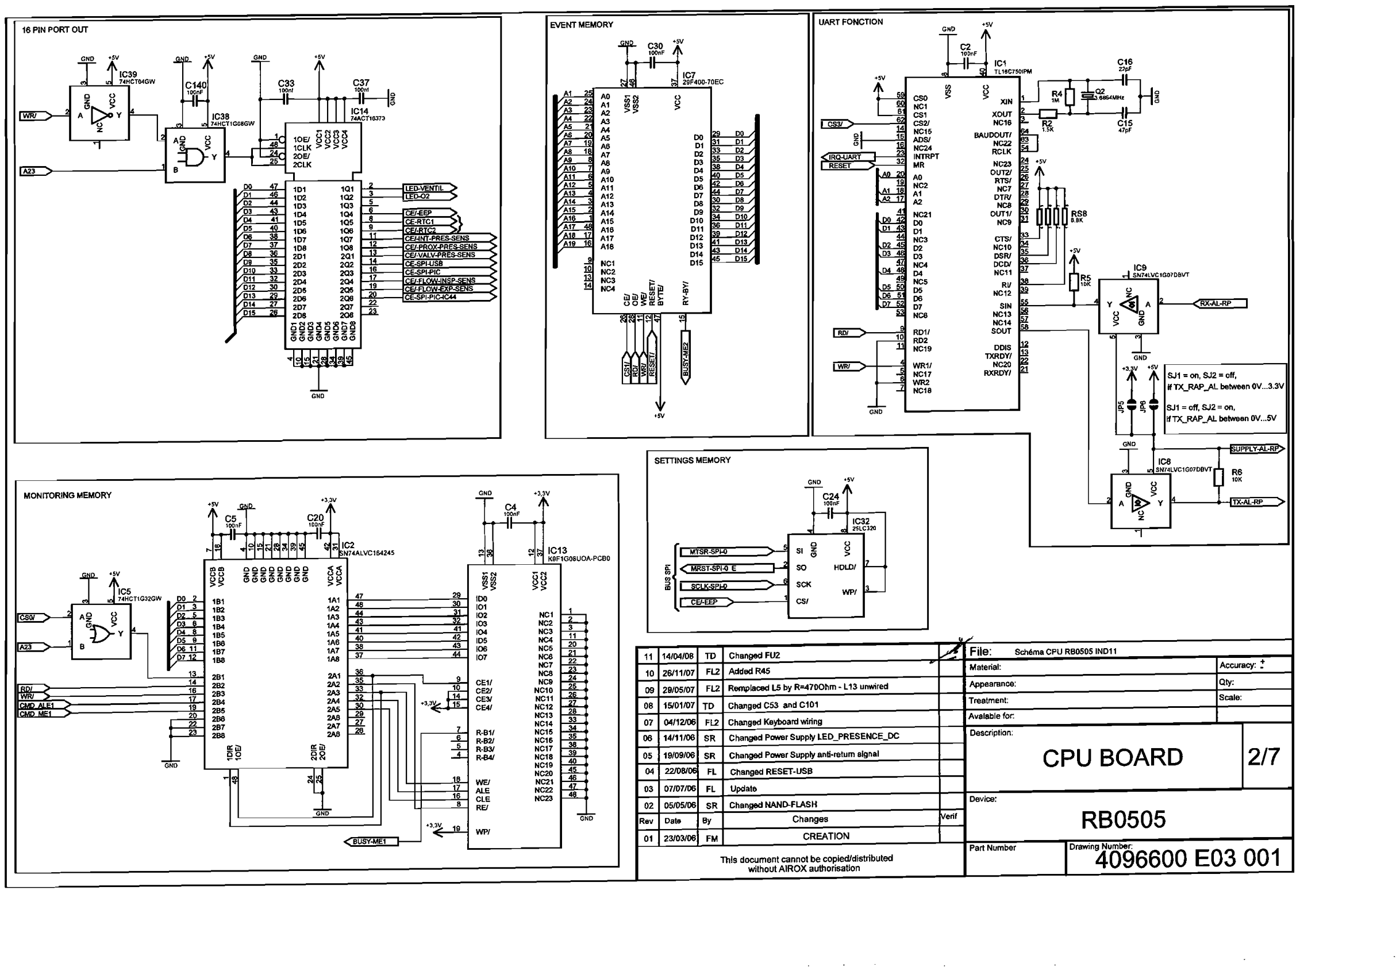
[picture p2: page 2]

1 100
105 lQ5
lm | | 1-
107 lQ7
108 | 108 201 | 2Ql
202 2-
203 | 2Q3 2 | 200
205 2W

MONITORING MEMORY

# CPU BOARD

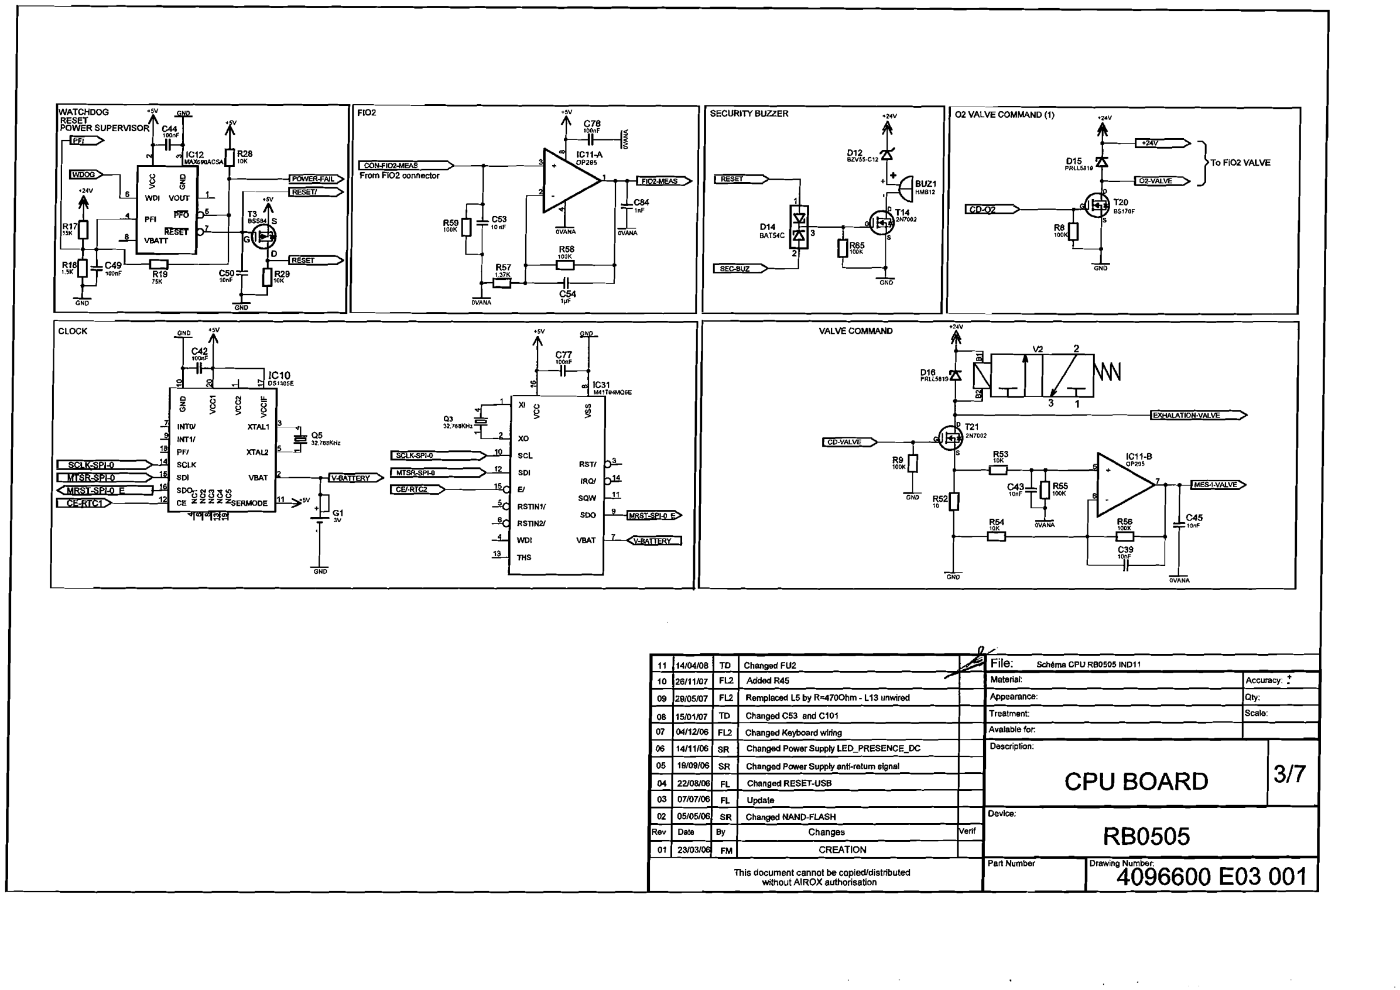
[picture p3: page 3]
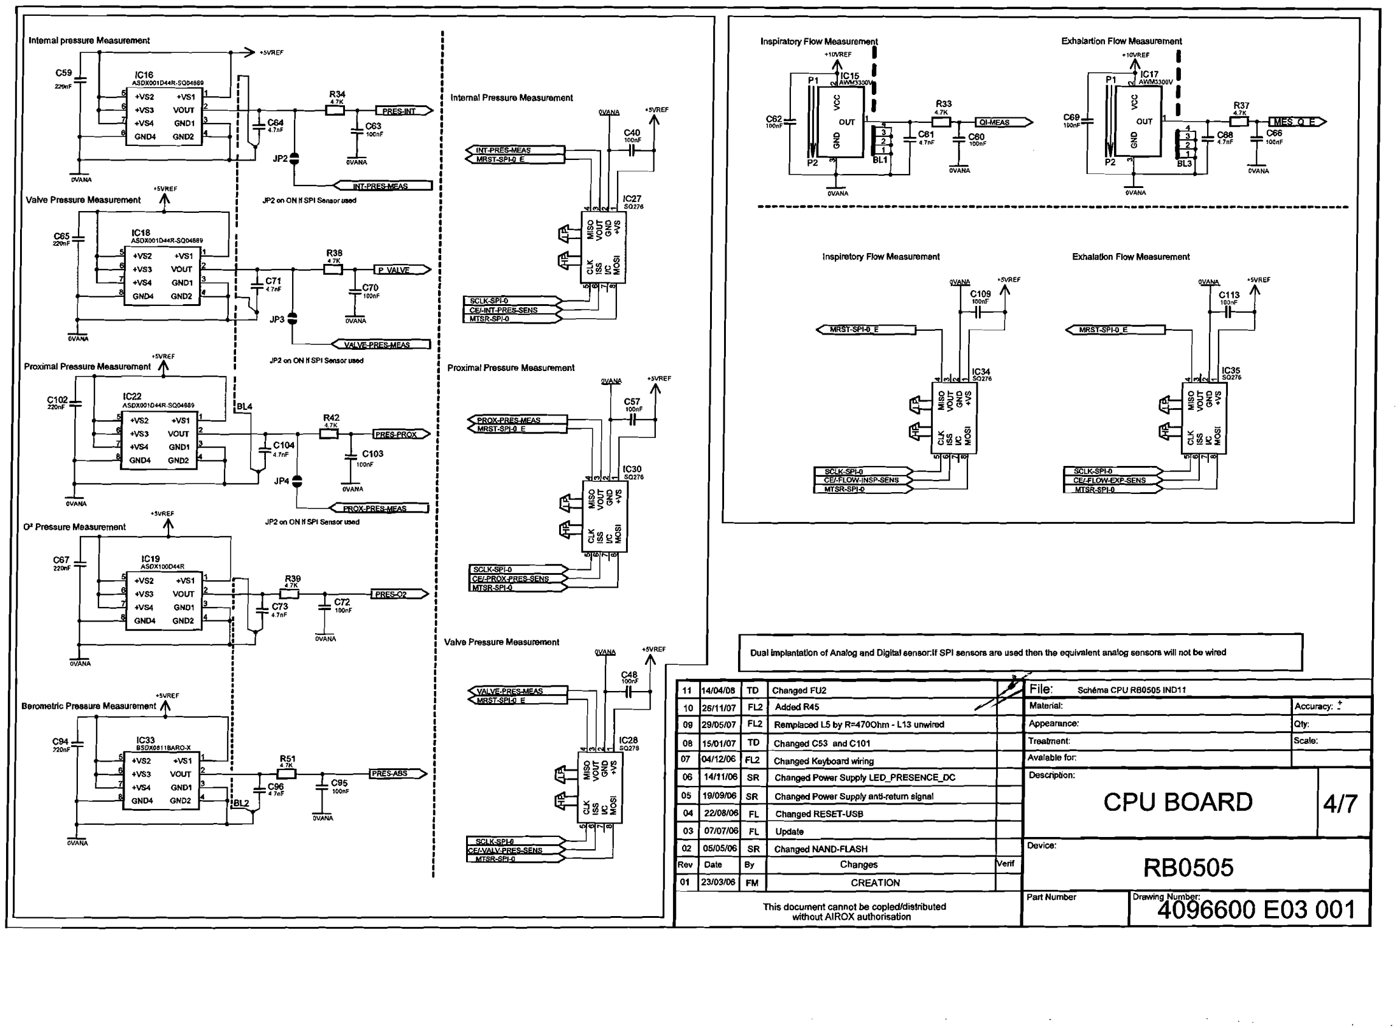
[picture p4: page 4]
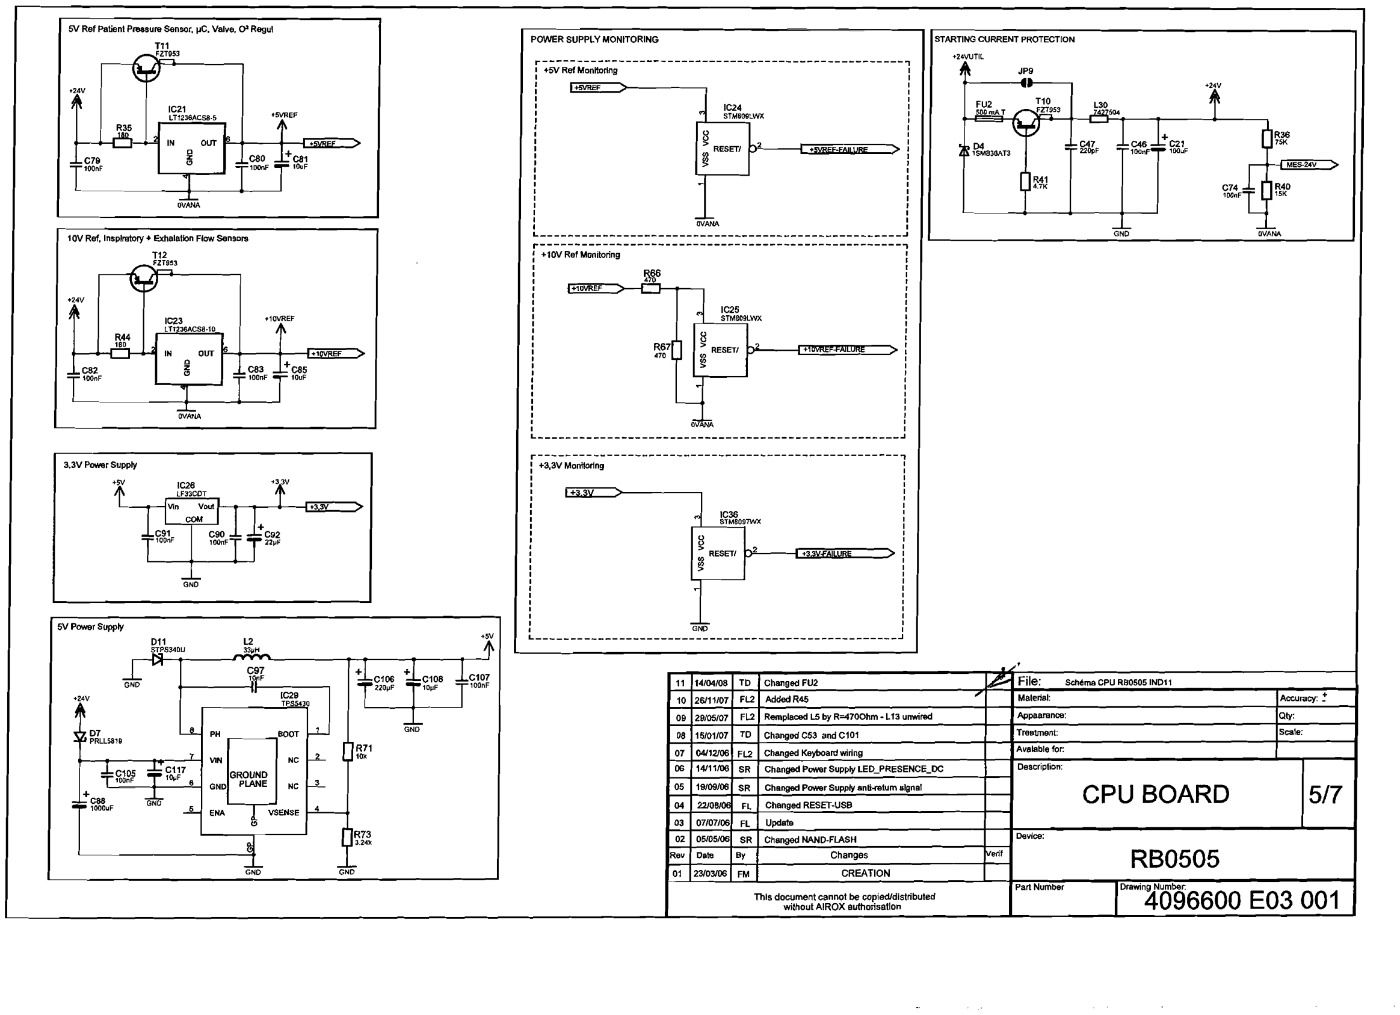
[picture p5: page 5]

( | 1 SV Rwf Paânt P-um | Senwrr. pC. Valve. W Rwgul | I
I I | I
1OV Rd. lnsplmtory + Exhalabn Flow Sanson | I
I | GND

POWER SUPPLY MONITORING

r----------------------------------------------------
: +1OV Re1 Monitoring | I

/?
File: | sdieme cpu ~eosos INDII
Maletisl: | (~ccuraq: f
OB 2BMSlo7 FL2 Remplad L5 by R4700hm - LI3 vmired | Appaaranm: | QtV:
08 15101107 TD Changed C53 and Cl01 | Trestmwnt: | Scdle:
07 04112106 FU | Chsnged Keyboaniwillng | Avalable for:
ffi lWlltC8 SR | Changed Paver Svpply LED-PRESENCE-DC | Description:
05 191081ffi SR | ChsM Power Supply anti-tum slgnsl
M WOBIffi FI. | Changed RESET-US0 | CPU BOARD | 517 -
03 07/07106 FL | UpdSl8 | 1 02 OWWffi SR Changed WD-FLASH | Cevice:
RBV Osie | By | Changes | vsdf
01 2YOYffi FM | CREATION
RB0505 Pari Number | Drawing Number

This document cannot be wpiedldistributed

without AIROX suihorisatlon | 1 4096600 E03 001

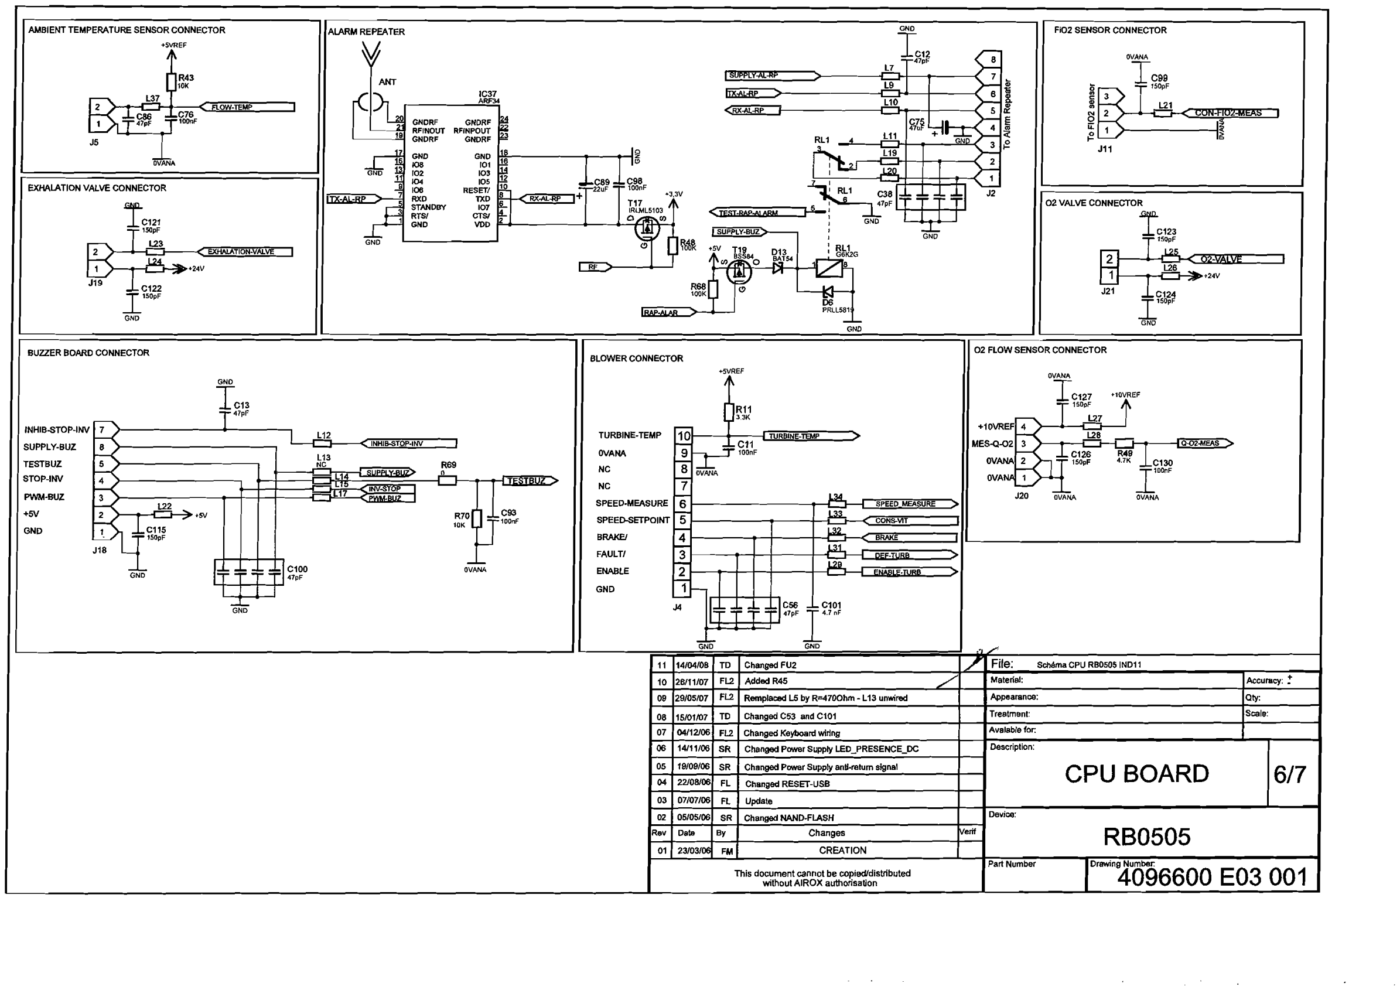
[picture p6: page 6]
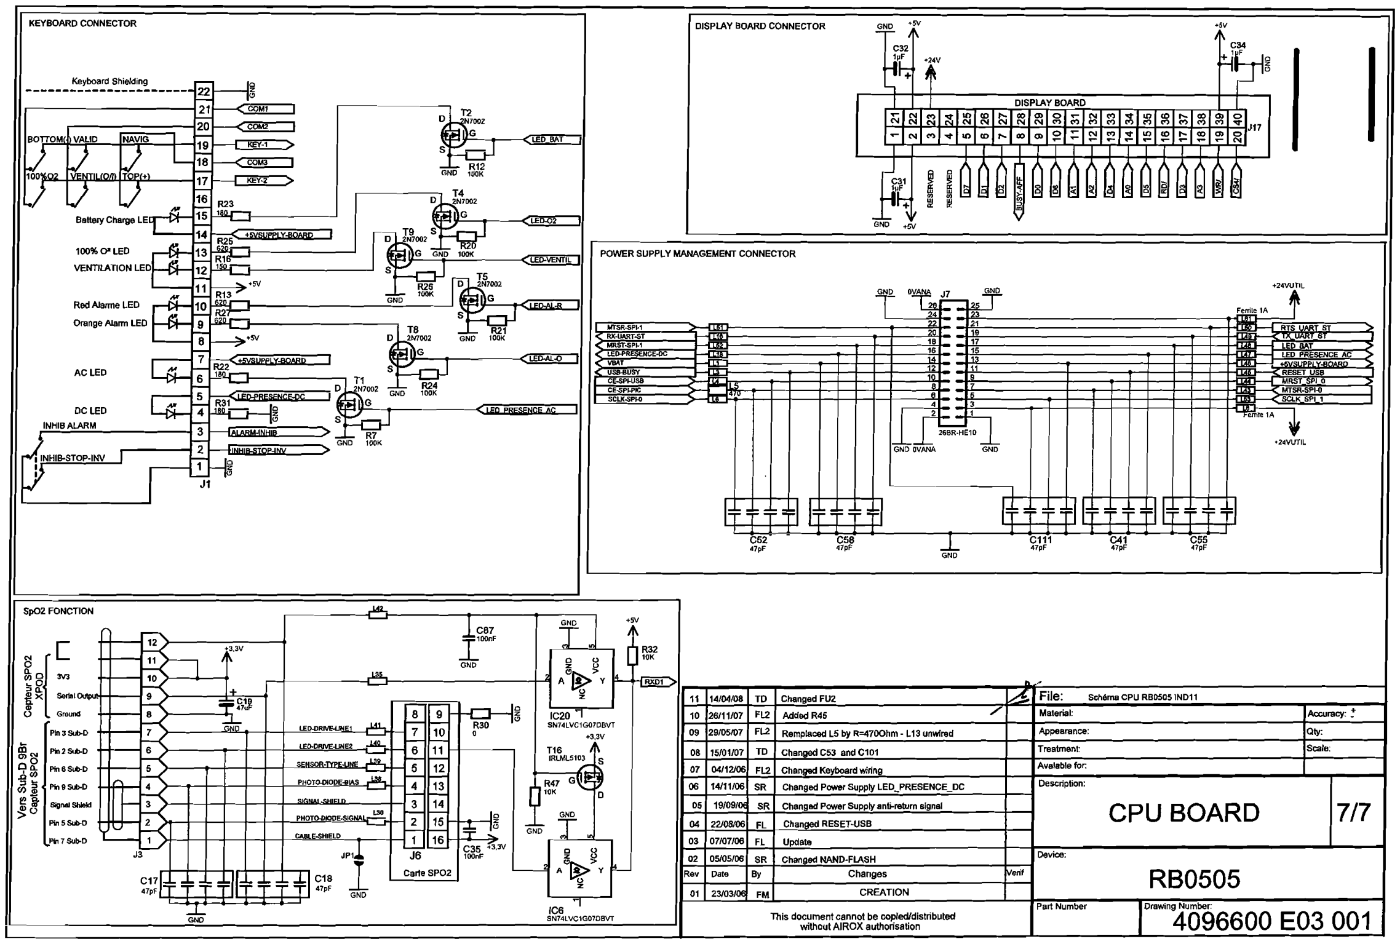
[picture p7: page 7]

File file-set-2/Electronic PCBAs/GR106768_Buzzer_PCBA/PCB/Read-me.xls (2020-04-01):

 | Customer : |  | COVIDIEN
 | Designation : |  | BUZZER BOARD
 | Schem No :
 | Board No : |  | GR106771 | Ind. / Rev. | A
 | FEE File No : |  | CN005 | Ind. / Rev. | A
 | Artwork : Extended GERBER
 | Layers |  | Files
 | Parts Top |  | GR106771-A-AST.phd
 | Silkscreen Top |  | GR106771-A-SST.(phd,pdf)
 | Solder Paste Top |  | GR106771-A-SPT.phd
 | Solder Mask Top |  | GR106771-A-SMT.phd
 | Copper Top |  | GR106771-A-CLT.phd
 | Internal Copper 2 |  | GR106771-A-CL2.phd
 | Internal Copper 3 |  | GR106771-A-CL3.phd
 | Internal Copper 4
 | Internal Copper 5
 | Internal Copper 6
 | Internal Copper 7
 | Internal Copper 8
 | Internal Copper 9
 | Internal Copper 10
 | Internal Copper 11
 | Copper Bottom |  | GR106771-A-CLB.phd
 | Solder Mask Bottom |  | GR106771-A-SMB.phd
 | Solder Paste Bottom
 | Silkscreen Bottom |  | GR106771-A-SSB.(phd,pdf)
 | Parts Bottom |  | GR106771-A-ASB.phd
 | Outline |  | GR106771-A-OUT.phd
 | Holes |  | Non Plated Holes | Plated Holes
 | EXCELLON drill file |  |  | GR106771-A-PTH.drd
 | Drill tool list |  |  | GR106771-A-PTH.drl
 | Manufacturing |  | Files
 | Drill drawing |  | GR106771-PPD-A.(pdf,hpg,dxf)
 | Assembly drawing |  | GR106771-PEQ-A.(pdf,hpg,dxf)
 | Partlist |  | GR106771-A-partlist.doc
 | ASCII data |  | GR106771-A.(pcf,ftf)
 | IDF data |  | GR106771-A.(pro,brd)
 | Archive file Name : |  | GR106771-AI-A.zip
 |  | Files for manufacturing printed circuit |  |  | 2014-03-20
 |  |  |  |  | Page : 1/1
 |  | GR106771-A |  |  | CN005
France Etudes Electroniques Rue Jules Ferry 24130 - PRIGONRIEUX Tél: 05.53.24.63.11 Fax: 05.53.24.67.28 E-mail : fee@fee.fr

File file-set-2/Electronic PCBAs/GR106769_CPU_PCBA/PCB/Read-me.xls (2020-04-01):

 | Customer : |  | COVIDIEN
 | Designation : |  | CPU BOARD
 | Schem No :
 | Board No : |  | GR106772 | Ind. / Rev. | A
 | FEE File No : |  | CN004 | Ind. / Rev. | A
 | Artwork : Extended GERBER
 | Layers |  | Files
 | Parts Top |  | GR106772-A-CST.phd
 | Silkscreen Top |  | GR106772-A-SST.(phd,pdf)
 | Solder Paste Top |  | GR106772-A-SPT.phd
 | Solder Mask Top |  | GR106772-A-SMT.phd
 | Copper Top |  | GR106772-A-CLT.phd
 | Internal Copper 2 |  | GR106772-A-CL2.phd
 | Internal Copper 3 |  | GR106772-A-CL3.phd
 | Internal Copper 4 |  | GR106772-A-CL4.phd
 | Internal Copper 5 |  | GR106772-A-CL5.phd
 | Internal Copper 6
 | Internal Copper 7
 | Internal Copper 8
 | Internal Copper 9
 | Internal Copper 10
 | Internal Copper 11
 | Copper Bottom |  | GR106772-A-CLB.phd
 | Solder Mask Bottom |  | GR106772-A-SMB.phd
 | Solder Paste Bottom |  | GR106772-A-SPB.phd
 | Silkscreen Bottom |  | GR106772-A-SSB.(phd,pdf)
 | Parts Bottom |  | GR106772-A-CSB.phd
 | Outline |  | GR106772-A-OUT.phd
 | Holes |  | Non Plated Holes | Plated Holes
 | EXCELLON drill file |  | GR106772-A-NPTH.drd | GR106772-A-PTH.drd
 | Drill tool list |  | GR106772-A-NPTH.drl | GR106772-A-PTH.drl
 | Manufacturing |  | Files
 | Drill drawing |  | GR106772-PPD-A.(pdf,hpg,dxf)
 | Assembly drawing |  | GR106772-PEQ-A.(pdf,hpg,dxf)
 | Partlist |  | GR106772-A-partlist.doc
 | ASCII data |  | GR106772-A.(pcf,ftf)
 | IDF data |  | GR106772-A.(pro,brd)
 | Archive file Name : |  | GR106772-AI-A.zip
 |  | Files for manufacturing printed circuit |  |  | 2014-03-19
 |  |  |  |  | Page : 1/1
 |  | GR106772-A
France Etudes Electroniques Rue Jules Ferry 24130 - PRIGONRIEUX Tél: 05.53.24.63.11 Fax: 05.53.24.67.28 E-mail : fee@fee.fr

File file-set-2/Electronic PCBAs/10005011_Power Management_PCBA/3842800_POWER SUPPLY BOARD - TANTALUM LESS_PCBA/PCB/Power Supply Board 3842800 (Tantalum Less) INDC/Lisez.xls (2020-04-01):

 | Client : | AIROX
 | Désignation : | Carte Power Supply 3842800 (Tantalum less) INDC
 | Réf. schéma : | xx |  |  | Indice :
 | Réf.circuit : | 4096600 E07 002 |  |  | Indice : | C
 |  | Référence dossier FEE : |  | 1008087 | Indice : C
 | Phototraçage : GERBER étendu
 | Couches |  | Fichiers
 | Sérigraphie Face compos. |  | sefc.phd + sefc.pdf
 | Pâte à braser Fc |  | pabc.phd
 | Vernis épargne Fc |  | vec.phd
 | Ci face composants |  | fc.phd
 | Couche interne 2 |  | f2.phd
 | Couche interne 3 |  | f3.phd
 | Couche interne 4 |  | f4.phd
 | Couche interne 5 |  | f5.phd
 | Couche interne 6
 | Couche interne 7
 | Couche interne 8
 | Couche interne 9
 | Couche interne 10
 | Couche interne 11
 | Ci face soudures |  | fs.phd
 | Vernis épargne Fs |  | ves.phd
 | Pâte à braser Fs |  | pabs.phd
 | Sérigraphie Face Soudures |  | sefs.phd + sefs.pdf
 | Détourage |  | det.phd
 | Perçage |  | Trous Non Métallisés |  | Trous Métallisés
 | Fichiers de perçage |  | per1.drd |  | per0.drd
 | Rapports de perçage |  | per1.drl |  | per0.drl
 | Dossier de fabrication |  | Fichiers
 | Cahier des charges |  | CdC Routage Power Supply Board 3842800 (Tantalum less) INDC.doc
 | Plan de perçage |  | per.(hpg,pdf,dxf)
 | Plan d'équipement Fc |  | eqfc.(hpg,pdf,phd,dxf)
 | Plan d'équipement Fs |  | eqfs.(hpg,pdf,phd,dxf)
 | Fichier Netlist |  | net.ccf
 | coordonnées composants |  | partslist.rep
 | Fichier ASCII |  | powersupply-c.(pcf + ftf)
 | Fichier IDF |  | powersupply-c.(brd+pro)
 | Nom du fichier d'archive: Power Supply Board 3842800 (Tantalum less) INDC.zip
 |  | Fichiers de fabrication de circuit imprimé |  |  |  |  | 2010-08-27
 |  |  |  |  |  |  | Page : 1/1
 |  | Carte Power Supply 3842800 (Tantalum less) INDC |  |  |  |  | 1008087
 |  | AIROX
France Etudes Electroniques |  | Rue Jules Ferry 24130 - PRIGONRIEUX Tél: 05.53.24.63.11 Fax: 05.53.24.67.28 E-mail : fee@fee.fr

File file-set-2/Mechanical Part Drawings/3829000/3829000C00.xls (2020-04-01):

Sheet: 3829000-A
3829000-A
X | Y
0 | 0
0.5 | 0
1 | 0
1.5 | 0
2 | 0
2.5 | 0
3 | 0
3.5 | 0
4 | 0
4.5 | 0
5 | 0
5.5 | 0
6 | 0
6.5 | 0
7 | 0
7.5 | 0
8 | 0
8.5 | 0
9 | 0
9.5 | 0
10 | 0
10.5 | 0
11 | 0
11.5 | 0
12 | 0
12.5 | 0
13 | 0
13.5 | 0
14 | 0
14.5 | 0
15 | 0
15.5 | 0
16 | 0
16.5 | 0
17 | 0
17.5 | 0
18 | 0
18.5 | 0
19 | 0
19.5 | 0
20 | 0
20.5 | 0
21 | 0
21.5 | 0
22 | 0
22.5 | 0
23 | 0
23.5 | 0
24 | 0
24.5 | 0
25 | 0
25.5 | 0
26 | 0
26.5 | 0
27 | 0
27.5 | 0
28 | 0
28.5 | 0
29 | 0
29.5 | 0
30 | 0
30.5 | 0
31 | 0
31.5 | 0
32 | 0
32.5 | 0
33 | 0
33.5 | 0
34 | 0
34.5 | 0
35 | 0
35.5 | 0
36 | 0
36.5 | 0
37 | 0
37.5 | 0
38 | 0
38.5 | 0
39 | 0
39.5 | 0
40 | 0
40.5 | 0
41 | 0
41.5 | 0
42 | 0
42.5 | 0
43 | 0
43.5 | 0
44 | 0
44.5 | 0
45 | 0
45.5 | 0
46 | 0
46.5 | 0
47 | 0
47.5 | 0
48 | 0
48.5 | 0
49 | 0
49.5 | 0
50 | 0
50.5 | 0
51 | 0
51.5 | 0
52 | 0
52.5 | 0
53 | 0
53.5 | 0
54 | 0
54.5 | 0
55 | 0
55.5 | 0
56 | 0
56.5 | 0
57 | 0
57.5 | 0
58 | 0
58.5 | 0
59 | 0
59.5 | 0
60 | 0
60.5 | 0
61 | 0
61.5 | 0
62 | 0
62.5 | 0
63 | 0
63.5 | 0
64 | 0
64.5 | 0
65 | 0
65.5 | 0
66 | 0
66 | 0.5
66 | 1
66 | 1.5
66 | 2
66 | 2.5
66 | 3
66 | 3.5
66 | 4
66 | 4.5
66 | 5
66 | 5.5
66 | 6
66 | 6.5
66 | 7
66 | 7.5
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

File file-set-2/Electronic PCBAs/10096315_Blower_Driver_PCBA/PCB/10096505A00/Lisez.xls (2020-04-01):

 | Client : | COVIDIEN
 | Désignation : | Carte Commande Turbine RB0505 A
 | Réf. schéma : | xx |  |  | Indice :
 | Réf.circuit : | 10096505 |  |  | Indice : | A
 |  | Référence dossier FEE : |  | 1008088 | Indice : A
 | Phototraçage : GERBER étendu
 | Couches |  | Fichiers
 | Sérigraphie Face compos. |  | sefc.phd + sefc.pdf
 | Pâte à braser Fc |  | pabc.phd
 | Vernis épargne Fc |  | vec.phd
 | Ci face composants |  | fc.phd
 | Couche interne 2 |  | f2.phd
 | Couche interne 3 |  | f3.phd
 | Couche interne 4
 | Couche interne 5
 | Couche interne 6
 | Couche interne 7
 | Couche interne 8
 | Couche interne 9
 | Couche interne 10
 | Couche interne 11
 | Ci face soudures |  | fs.phd
 | Vernis épargne Fs |  | ves.phd
 | Pâte à braser Fs |  | pabs.phd
 | Sérigraphie Face Soudures |  | sefs.phd + sefs.pdf
 | Détourage |  | det.phd
 | Perçage |  | Trous Non Métallisés |  | Trous Métallisés
 | Fichiers de perçage |  |  |  | per0.drd
 | Rapports de perçage |  |  |  | per0.drl
 | Dossier de fabrication |  | Fichiers
 | Plan de perçage |  | per.(hpg,pdf,dxf)
 | Plan d'équipement Fc |  | eqfc.(hpg,pdf,phd,dxf)
 | Plan d'équipement Fs |  | eqfs.(hpg,pdf,phd,dxf)
 | coordonnées composants |  | partslist.doc
 | Fichier ASCII |  | ctrb0505-A.(pcf + ftf)
 | Fichier IDF |  | ctrb0505-A.(brd+pro)
 | Nom du fichier d'archive: 10096505-A.zip
 |  | Fichiers de fabrication de circuit imprimé |  |  |  |  | 2012-08-01
 |  |  |  |  |  |  | Page : 1/1
 |  | Carte Commande Turbine RB0505 A |  |  |  |  | 1008088
 |  | AIROX
France Etudes Electroniques |  | Rue Jules Ferry 24130 - PRIGONRIEUX Tél: 05.53.24.63.11 Fax: 05.53.24.67.28 E-mail : fee@fee.fr

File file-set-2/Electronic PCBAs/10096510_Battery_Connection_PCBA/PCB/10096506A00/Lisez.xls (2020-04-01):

 | Client : | COVIDIEN
 | Désignation : | Carte Connection Batterie RB0505 A
 | Réf. schéma : | xx |  |  | Indice :
 | Réf.circuit : | 10096506 |  |  | Indice : | A
 |  | Référence dossier FEE : |  | 1008084 | Indice : A
 | Phototraçage : GERBER étendu
 | Couches |  | Fichiers
 | Sérigraphie Face compos. |  | sefc.phd + sefc.pdf
 | Pâte à braser Fc |  | pabc.phd
 | Vernis épargne Fc |  | vec.phd
 | Ci face composants |  | fc.phd
 | Couche interne 2
 | Couche interne 3
 | Couche interne 4
 | Couche interne 5
 | Couche interne 6
 | Couche interne 7
 | Couche interne 8
 | Couche interne 9
 | Couche interne 10
 | Couche interne 11
 | Ci face soudures |  | fs.phd
 | Vernis épargne Fs |  | ves.phd
 | Pâte à braser Fs |  | pabs.phd
 | Sérigraphie Face Soudures |  | sefs.phd + sefs.pdf
 | Détourage |  | det.phd
 | Perçage |  | Trous Non Métallisés |  | Trous Métallisés
 | Fichiers de perçage |  | per1.drd |  | per0.drd
 | Rapports de perçage |  | per1.drl |  | per0.drl
 | Dossier de fabrication |  | Fichiers
 | Plan de perçage |  | per.(hpg,pdf,dxf)
 | Plan d'équipement Fc |  | eqfc.(hpg,pdf,phd,dxf)
 | Plan d'équipement Fs |  | eqfs.(hpg,pdf,phd,dxf)
 | coordonnées composants |  | partslist.doc
 | Fichier ASCII |  | cbr0505-A.(pcf + ftf)
 | Fichier IDF |  | cbr0505-A.(brd+pro)
 | Nom du fichier d'archive: 10096506-A.zip
 |  | Fichiers de fabrication de circuit imprimé |  |  |  |  | 2012-08-13
 |  |  |  |  |  |  | Page : 1/1
 |  | Carte Connection Batterie RB0505 A |  |  |  |  | 1008084
 |  | COVIDIEN
France Etudes Electroniques |  | Rue Jules Ferry 24130 - PRIGONRIEUX Tél: 05.53.24.63.11 Fax: 05.53.24.67.28 E-mail : fee@fee.fr

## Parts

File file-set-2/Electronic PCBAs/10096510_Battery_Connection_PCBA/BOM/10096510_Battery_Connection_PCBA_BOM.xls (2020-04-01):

Creator | Jenaro | Julio
Type
Description
Title Block
Item Number | Description | Subclass | Lifecycle Phase | Rev | Rev Incorp Date | Rev Release Date | Effectivity Date
10096510 | BATTERY CONNECTION CARD RB0505 | Part | Production | A ECO-R252633 | 31/Jul/2013 05:52:42 PM BST | 06/Jan/2015 04:58:11 PM GMT
Page Two
UOM | Additional Categories Part | Alternate Part(s) | Alternate FG Part(s) | Restricted Access | Vendor User Group | Data Classification | Attachment Destination | Created By | Create Date | Legacy Data Source | Divesture Destination
Each | PART CATEGORY|Pc Board |  |  |  | V - Jabil SH | Confidential |  | Searcy, Teresa | 12/Jun/2012 01:54:35 PM BST | Agile RMS
Page Three
Product Family(s) | Item Type | Lot Serial Control | Document Number | RoHS Compliant | Bio Approval Number | Integration Description | Project(s) | Notes | Handling/Storage | Legacy Number
 | Customized | None | NODOCUMENT | Unknown |  | BATTERY CONNECTION CARD RB0505 | RSP - PB560-520 | Product Family : RSP - VENTILATOR SYSTEMS, Commodity Code: BPCS Add-Updt : FC02.17, Country of Origin: BPCS Add : FR = FRANCE, Shelf Life Days:BPCS Add-Updt : 0, Must Single Issue: BPCS Add : NO, Item Class: BPCS Add-Updt : GL-66 PB500 Series Ventilators/Gen 1, Controlled AML? : YES
BOM
Level | Attachments (Image) | Manufacturer (Image) | Pending Changes (Image) | Has Been Redlined (Image) | Has Quality(Image) | Bubble Number | Item Number | Item Description | Item Rev | Qty | UOM | Item Lifecycle Phase | BOM Notes | Ref Des | Component Effective From | Component Discontinue Date | Alternate Part(s) | Alternate FG Part(s) | Alternate Document(s) | Subclass | Sites | Planned? | Scrap Factor | OP # | Thumbnail | Attachments(Image) | Manufacture Part Has Redline | Mfr. Name | Mfr. Part Number | Mfr. Part Description | Mfr. Part Lifecycle Phase | Preferred Status | Sites | Reference Notes | RoHS Compliant? | RoHS Compliance Statement
1 | true | true | true | false | false | 0 | 10022508 | CAPACITOR CERAMIC,10NF,+/-10%,50V,0603 | C ECO-R252633 | 2 | Each | Production |  | C1,C2 |  |  |  |  |  | Part | BDRM |  | 1 |  |  | true | false | YAGEO_RMS1 | 223858615636 | CAPACITOR, CERAMIC, MULTILAYER, 50 V, X7R, 0.01 UF, SURFACE MOUNT, 0603 | Active | Preferred |  | BRAND: PHYCOMP | Yes | Legacy Inventory Status: Cleared
 |  |  |  |  |  |  |  |  |  |  |  |  |  |  |  |  |  |  |  |  |  |  |  |  |  | true | false | YAGEO_RMS1 | 223858615536 | CAPACITOR, CERAMIC, MULTILAYER, 50 V, X7R, 0.01 UF, SURFACE MOUNT, 0603 | Active | Preferred |  | BRAND: PHYCOMP | Yes | Legacy Inventory Status: Cleared
 |  |  |  |  |  |  |  |  |  |  |  |  |  |  |  |  |  |  |  |  |  |  |  |  |  | true | false | KEMET_RMS1 | C0603C103K5RACTU | CERAMIC CHIP CAPACITOR | Active | Preferred |  |  | Yes | Legacy Inventory Status: Cleared
 |  |  |  |  |  |  |  |  |  |  |  |  |  |  |  |  |  |  |  |  |  |  |  |  |  | true | false | YAGEO_RMS1 | CC0603KRX7R9BB103 | CAPACITOR, CERAMIC, MULTILAYER, 50 V, X7R, 0.01 UF, SURFACE MOUNT, 0603 | Active | Preferred |  |  | Yes | Legacy Inventory Status: Cleared
1 | true | true | false | false | false | 0 | 10022532 | FILTER CC, 1MHZ-1GHZ, 10A, 50V | B EC130338 | 1 | Each | Production |  | FI1 |  |  |  |  |  | Part | BDRM |  | 1 |  |  | true | false | MURATA MANUFACTURING CO., LTD. | BNX002-01 | FILTER | Active | Preferred |  | ROHS EXEMPTION: 7(C)-1 | Yes - by exemption | Legacy Inventory Status: Cleared
 |  |  |  |  |  |  |  |  |  |  |  |  |  |  |  |  |  |  |  |  |  |  |  |  |  | true | false | MURATA MANUFACTURING CO., LTD. | BNX00201 | NOISE/EMI SUPPRESSION FILTER | Active | Preferred |  | ROHS EXEMPTION: 7(C)-1 | Yes - by exemption | Legacy Inventory Status: Cleared
 |  |  |  |  |  |  |  |  |  |  |  |  |  |  |  |  |  |  |  |  |  |  |  |  |  | true | false | MURATA MANUFACTURING CO., LTD. | BNX002-11 | NOISE/EMI SUPPRESSION FILTER | Active | Preferred |  |  | Yes | CLEARED
1 | true | true | false | false | false | 0 | 10022623 | CAPACITOR,47 PF,+/-5%,50V,0402 | C ECO-R252636 | 2 | Each | Production |  | C3,C4 |  |  |  |  |  | Part | BDRM |  | 1 |  |  | true | false | KEMET_RMS1 | C0402C470J5GAC | CAP,CER,SMT,0402,5%,50V,47PF | Active | Preferred |  |  | Yes | Legacy Inventory Status: Cleared
 |  |  |  |  |  |  |  |  |  |  |  |  |  |  |  |  |  |  |  |  |  |  |  |  |  | true | false | SAMSUNG_RMS1 | CL05C470JB5NNNC | CAP CER 47PF 50V 5% NP0 0402 | Active | Preferred |  |  | Yes | Legacy Inventory Status: Cleared
 |  |  |  |  |  |  |  |  |  |  |  |  |  |  |  |  |  |  |  |  |  |  |  |  |  | true | false | MURATA MANUFACTURING CO., LTD. | GRM1555C1H470JA01D | CAP CER 47PF 50V 5% NP0 0402 | Active | Preferred |  |  | Yes | Legacy Inventory Status: Cleared
 |  |  |  |  |  |  |  |  |  |  |  |  |  |  |  |  |  |  |  |  |  |  |  |  |  | true | false | KEMET_RMS1 | C0402C470J5GACTU | CAP,CER,SMT,0402,5%,50V,47PF | Active | Preferred |  | TAPE & REEL | Yes | Legacy Inventory Status: Cleared
 |  |  |  |  |  |  |  |  |  |  |  |  |  |  |  |  |  |  |  |  |  |  |  |  |  | true | false | MURATA MANUFACTURING CO., LTD. | GRM1555C1H470JZ01D | MONOLITHIC CERAMIC CAPACITOR | Active | Preferred |  |  | Yes | Legacy Inventory Status: Cleared
1 | true | true | false | false | false | 0 | 10022907 | SMD FERRITE 200MA | B ECO-R252636 | 2 | Each | Production |  | FI2,FI3 |  |  |  |  |  | Part | BDRM |  | 1 |  |  | true | false | WURTH ELEKTRONIK GMBH | 74279266 | MULTILAYER-SMD-FERRITE | Active | Preferred |  | ROHS EXEMPT : 7(C)-1 | Yes | Legacy Inventory Status: Cleared
1 | true | true | true | false | false | 0 | 10023418 | CONNECTOR, 10 CONTACTS, HE10 | A ECO-R252633 | 1 | Each | Production |  | J1 |  |  |  |  |  | Part | BDRM |  | 1 |  |  | true | false | HARTING | 09185107323 | CONNECTOR | Active | Preferred |  |  | Yes | Legacy Inventory Status: Cleared
1 | true | true | false | false | false | 0 | 10023419 | CONNECTOR, 1 CONTACTS, TEST PROBE | A ECO-R252636 | 1 | Each | Production |  | J6 |  |  |  |  |  | Part | BDRM |  | 1 |  |  | true | false | INGUN | GKS 913 305 230 A 15 02 S | TEST PROBE | Active | Preferred |  |  | Yes | Legacy Inventory Status: Cleared
1 | true | true | false | false | false | 0 | 10023420 | CONNECTOR, 2 CONTACTS, PIN SPACE 2.54, SM | B ECO-R252636 | 3 | Each | Production |  | J3,J4,J5 |  |  |  |  |  | Part | BDRM |  | 1 |  |  | true | false | PRECI-DIP (015220) | 811-S1-002-30-014101 |  | Active | Preferred |  | ROHS EXEMPTION: 6(C) | Yes - by exemption | Legacy Inventory Status: Cleared
1 | true | true | true | false | false | 0 | 10096506 | PRINTED CIRCUIT, BATTERY BOARD | A MC002637 | 1 | Each | Production |  |  |  |  |  |  |  | Part | BDRM |  | 1 |  |  | true | false | TTM | 10096506 |  | Active | Preferred |  |  | Yes | Legacy Inventory Status: Cleared
1 | true | false | true | false | false | 0 | 4096600.E01.001 | BATTERY CONNECTION BOARD SCH | 02 ECO-R256396 | 1 |  | Production |  |  |  |  |  |  |  | Document | BDRM |  | 1
1 | true | true | true | false | false | 1 | 3838600 | PC BOARD TRACABILITY LABEL | C ECO-R252633 | 1 | Each | Production |  |  |  |  |  |  |  | Part | BDRM |  | 1 |  |  | true | false | BRADY_RMS1 | 3838600-H | B-727 LABEL, POLYIMIDE, GLOSSY WHITE THERMAL TRANSFER PRINTABLE LABEL STOCK | Active | Preferred |  | CUSTOM LABEL PER COVIDIEN DRAWING 3838600 | Yes | Legacy Inventory Status: Cleared
Manufacturers
Attachments(Image) | Manufacture Part Has Redline | Mfr. Name | Mfr. Part Number | Mfr. Part Description | Mfr. Part Lifecycle Phase | Preferred Status | Sites | Reference Notes | RoHS Compliant? | RoHS Compliance Statement
true | false | JABIL SUPPLIER - SHANGHAI UPP CO.,LTD.(LOC) | 10096510 |  | Active | Preferred |  | CUSTOM PART PER COVIDIEN P/N 10096510 | Yes | Legacy Inventory Status: Cleared
Attachments
Is Checked Out | Has Been Redlined | Filename | File Description | File Size | File Type | Attachment Type | Modified Date | Last View Date | Checkout User | Checkout Date | Checkout Location | Checkin User | Folder Number | Folder Version
false | false | 10096510_A_ECO-R231090.pdf | RMS Historical PDF - ECO-R231090 | 101554 | pdf |  | 17/Aug/2015 04:53:42 PM BST | 17/Aug/2015 04:53:42 PM BST |  |  |  | Migration, Data | FF0009842505 | 1
false | false | 10096510_A_ECO-R252633.pdf | RMS Historical PDF - ECO-R252633 | 101542 | pdf |  | 17/Aug/2015 04:53:43 PM BST | 17/Aug/2015 04:53:43 PM BST |  |  |  | Migration, Data | FF0009842506 | 1
false | false | 10096510X01.PDF | Redlined Rev-X01 to Rev-A | 49013 | PDF |  | 17/Jun/2015 06:58:52 AM BST | 17/Jun/2015 06:58:52 AM BST |  |  |  | Migration, Data | FF0007735014 | 1
false | false | 10096510A00.PDF | Approved Rev-A | 59009 | PDF |  | 17/Jun/2015 06:58:52 AM BST | 17/Jun/2015 06:58:52 AM BST |  |  |  | Migration, Data | FF0007735012 | 1
false | false | 10096510A00.zip | Approved Rev-A, Source Files | 1266803 | zip |  | 17/Jun/2015 06:58:52 AM BST | 17/Jun/2015 06:58:52 AM BST |  |  |  | Migration, Data | FF0007735017 | 1

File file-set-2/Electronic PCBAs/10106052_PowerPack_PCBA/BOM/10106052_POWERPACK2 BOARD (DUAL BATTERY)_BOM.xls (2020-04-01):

Creator | Jenaro | Julio
Type
Description
Title Block
Item Number | Description | Subclass | Lifecycle Phase | Rev | Rev Incorp Date | Rev Release Date | Effectivity Date
10106052 | POWERPACK2 BOARD (DUAL BATTERY) | Part | Production | C ECO-R252636 | 05/Sep/2014 02:25:25 PM BST | 06/Jan/2015 05:10:58 PM GMT
Page Two
UOM | Additional Categories Part | Alternate Part(s) | Alternate FG Part(s) | Restricted Access | Vendor User Group | Data Classification | Attachment Destination | Created By | Create Date | Legacy Data Source | Divesture Destination
Each | PART CATEGORY|Pc Board |  |  |  | V - Jabil SH | Confidential |  | O'Connor, Martina | 07/Feb/2013 08:39:13 AM GMT | Agile RMS
Page Three
Product Family(s) | Item Type | Lot Serial Control | Document Number | RoHS Compliant | Bio Approval Number | Integration Description | Project(s) | Notes | Handling/Storage | Legacy Number
 | Customized | None | NODOCUMENT | Unknown |  | POWERPACK2 BOARD (DUAL BATTERY) | RSP - PB540 (ROHS N/A);RSP - PB560-520 | Product Family : RSP - VENTILATOR SYSTEMS, Commodity Code: BPCS Add-Updt : FC02.17, Country of Origin: BPCS Add : CN = CHINA, Shelf Life Days:BPCS Add-Updt : 0, Must Single Issue: BPCS Add : NO, Item Class: BPCS Add-Updt : GL-66 PB500 Series Ventilators/Gen 1
BOM
Level | Attachments (Image) | Manufacturer (Image) | Pending Changes (Image) | Has Been Redlined (Image) | Has Quality(Image) | Bubble Number | Item Number | Item Description | Item Rev | Qty | UOM | Item Lifecycle Phase | BOM Notes | Ref Des | Component Effective From | Component Discontinue Date | Alternate Part(s) | Alternate FG Part(s) | Alternate Document(s) | Subclass | Sites | Planned? | Scrap Factor | OP # | Thumbnail | Attachments(Image) | Manufacture Part Has Redline | Mfr. Name | Mfr. Part Number | Mfr. Part Description | Mfr. Part Lifecycle Phase | Preferred Status | Sites | Reference Notes | RoHS Compliant? | RoHS Compliance Statement
1 | true | true | false | false | false | 0 | 10000836 | RESISTOR 66,5K OHM, 0,063W, +/-0,1%, 0603 | A ECO-R252636 | 1 | Each | Production |  | R28 |  |  |  |  |  | Part | CBRM |  | 1 |  |  | true | false | WELWYN | PCF0603R-66K5BT1 |  | Active | Preferred |  |  | Yes | Legacy Inventory Status: Cleared
1 | true | true | false | false | false | 0 | 10000838 | RESISTOR 0,015 OHM, 2W, +/-1%, 2512 | A ECO-R252636 | 1 | Each | Production |  | R24 |  |  |  |  |  | Part | CBRM |  | 1 |  |  | true | false | WELWYN | LRF2512-R015FW |  | Active | Preferred |  | EXEMPTION LIST- 7(C)-I | Yes | Legacy Inventory Status: Cleared
1 | true | true | false | false | false | 0 | 10001204 | RES 100K OHM 1/10W 1% 0603 SMD | A MC002255 | 4 | Each | Production |  | R3,R11,R16,R27 |  |  |  |  |  | Part | CBRM |  | 1 |  |  | true | false | YAGEO_RMS1 | RC0603FR-07100KL | RESISTOR, METAL GLAZE/THICK FILM, 0.1 W, 1 %, 100 PPM, 100000 OHM, SURFACE MOUNT, 0603 | Active | Preferred |  |  | Yes - by exemption | RoHS compliant with 7(c)-I exemption and the exemption will be expired in 21 July 2021 for medical devices
 |  |  |  |  |  |  |  |  |  |  |  |  |  |  |  |  |  |  |  |  |  |  |  |  |  | true | false | PANASONIC_RMS1 | ERJ-3EKF1003V | RES 100K OHM 1/10W 1% 0603 SMD | Active | Preferred |  |  | Yes - by exemption | Rohs compliant with 7(c)-1 exemption and the exemption will be expired on 21/July/2021 for medical device
1 | false | true | false | false | false | 0 | 10002095 | MOSFET N-CH 60V 115MA SOT23-3 | C EC014944 | 5 | Each | Production |  | T1,T6,T7,T10,T15 |  |  |  |  |  | Part | CBRM |  | 1 |  |  | true | false | ON SEMICONDUCTOR | 2N7002LT1G | TRANS MOSFET N SOT23 | Active | Preferred |  |  | Yes | Per manufacturer RoHS and material declaration, part has a "G" prefix and does not contain any lead die. Thus, it is RoHS compliant with no exemptions.
 |  |  |  |  |  |  |  |  |  |  |  |  |  |  |  |  |  |  |  |  |  |  |  |  |  | true | false | DIODES INC | 2N7002-7-F | MOSFET N-CH 60V 115MA SOT23-3 | Active | Preferred |  |  | Yes | Legacy Inventory Status: Cleared
 |  |  |  |  |  |  |  |  |  |  |  |  |  |  |  |  |  |  |  |  |  |  |  |  |  | true | false | DIODES INC_RMS1 | 2N7002TA | MOSFET N-CH 60V 115MA SOT23-3 | Active | Preferred |  |  | Yes | Legacy Inventory Status: Cleared
1 | true | true | false | false | false | 0 | 10021053 | RELAY 24V 2POLES 8A RT2 | B ECO-R252636 | 1 | Each | Production |  | RL1 |  |  |  |  |  | Part | CBRM |  | 1 |  |  | true | false | FINDER | 41.52.9.024.0010 |  | Active | Preferred |  |  | Yes | Legacy Inventory Status: Cleared
1 | true | true | false | false | false | 0 | 10021070 | RESISTOR 40.2KOHM 0.1% 0.063W 0603 | A ECO-R252636 | 1 | Each | Production |  | R29 |  |  |  |  |  | Part | CBRM |  | 1 |  |  | true | false | WELWYN | PCF0603-R-40K2BT1 |  | Active | Preferred |  |  | Yes | Legacy Inventory Status: Cleared
1 | true | true | false | false | false | 0 | 10021350 | CONNECTOR 2 CONTACTS, 3.5A, HT 6.5MM | A ECO-R252636 | 6 | Each | Production |  | J1,J2,J3,J5,J6,J7 |  |  |  |  |  | Part | CBRM |  | 1 |  |  | true | false | ANTELEC | ACPD25410265 |  | Active | Alternate |  |  | Yes | Legacy Inventory Status: Cleared
 |  |  |  |  |  |  |  |  |  |  |  |  |  |  |  |  |  |  |  |  |  |  |  |  |  | true | false | PRECI-DIP (015220) | 811-S1-002-10-015101 |  | Active | Preferred |  | EXEMPTION LIST-EXCEPTION 6 | Yes - by exemption | Legacy Inventory Status: Cleared
1 | true | true | false | false | false | 0 | 10021365 | DIODE NETWORK ESD PROTECT 30 KV SOT457 | A ECO-R252636 | 4 | Each | Production |  | D10,D11,D12,D13 |  |  |  |  |  | Part | CBRM |  | 1 |  |  | true | false | NXP SEMICONDUCTORS_RMS1 | PESD5V0S4UD,115 | TVS DIODE 5V 13V 6TSOP | Active | Preferred |  |  | RoHS3 Compliant | Legacy Inventory Status: Cleared
1 | true | true | false | false | false | 0 | 10021369 | CAPACITOR CERAMIC 1UF 10V 10% X5R 0402 | A ECO-R252636 | 1 | Each | Production |  | C6 |  |  |  |  |  | Part | CBRM |  | 1 |  |  | true | false | KEMET_RMS1 | C0402C105K8PACTU |  | Active | Preferred |  |  | Yes | Legacy Inventory Status: Cleared
1 | true | true | false | false | false | 0 | 10021370 | CAPACITOR CERAMIC 10UF 6.3V 20% X5R 0603 | B ECO-R252636 | 2 | Each | Production |  | C2,C22 |  |  |  |  |  | Part | CBRM |  | 1 |  |  | true | false | KEMET_RMS1 | C0603C106M9PACTM |  | Active | Preferred |  |  | Yes | Legacy Inventory Status: Cleared
 |  |  |  |  |  |  |  |  |  |  |  |  |  |  |  |  |  |  |  |  |  |  |  |  |  | true | false | YAGEO_RMS1 | CC0603MRX5R5BB106 |  | Active | Preferred |  |  | Yes | Legacy Inventory Status: Cleared
 |  |  |  |  |  |  |  |  |  |  |  |  |  |  |  |  |  |  |  |  |  |  |  |  |  | true | false | MURATA_RMS1 | GRM188R60J106ME47D | CAPACITOR, 0603, 10UF, 6.3V | Active | Preferred |  |  | RoHS3 Compliant | Cleared
1 | true | true | false | false | false | 0 | 10021386 | CAPACITOR CERAMIC 100NF 50V 10% X7R 0603 | A ECO-R252636 | 10 | Each | Production |  | C1,C4,C5,C7,C11,C14,C23,C24,C25,C30 |  |  |  |  |  | Part | CBRM |  | 1 |  |  | true | false | KEMET_RMS1 | C0603C104K5RACTU | CAP,CER,SMT,0603,X7R,10%,50V,0.1UF | Active | Preferred |  |  | Yes | Legacy Inventory Status: Cleared
1 | true | true | true | false | false | 0 | 10022508 | CAPACITOR CERAMIC,10NF,+/-10%,50V,0603 | C ECO-R252633 | 2 | Each | Production |  | C10,C12 |  |  |  |  |  | Part | CBRM |  | 1 |  |  | true | false | YAGEO_RMS1 | 223858615636 | CAPACITOR, CERAMIC, MULTILAYER, 50 V, X7R, 0.01 UF, SURFACE MOUNT, 0603 | Active | Preferred |  | BRAND: PHYCOMP | Yes | Legacy Inventory Status: Cleared
 |  |  |  |  |  |  |  |  |  |  |  |  |  |  |  |  |  |  |  |  |  |  |  |  |  | true | false | YAGEO_RMS1 | 223858615536 | CAPACITOR, CERAMIC, MULTILAYER, 50 V, X7R, 0.01 UF, SURFACE MOUNT, 0603 | Active | Preferred |  | BRAND: PHYCOMP | Yes | Legacy Inventory Status: Cleared
 |  |  |  |  |  |  |  |  |  |  |  |  |  |  |  |  |  |  |  |  |  |  |  |  |  | true | false | KEMET_RMS1 | C0603C103K5RACTU | CERAMIC CHIP CAPACITOR | Active | Preferred |  |  | Yes | Legacy Inventory Status: Cleared
 |  |  |  |  |  |  |  |  |  |  |  |  |  |  |  |  |  |  |  |  |  |  |  |  |  | true | false | YAGEO_RMS1 | CC0603KRX7R9BB103 | CAPACITOR, CERAMIC, MULTILAYER, 50 V, X7R, 0.01 UF, SURFACE MOUNT, 0603 | Active | Preferred |  |  | Yes | Legacy Inventory Status: Cleared
1 | true | true | true | false | false | 0 | 10022515 | DIODE SCHOTTKY, 500MA,40V,SOD323 | C ECO-R252633 | 3 | Each | Production |  | D3,D4,D6 |  |  |  |  |  | Part | CBRM |  | 1 |  |  | true | false | NXP SEMICONDUCTORS_RMS1 | PMEG4005AEA,115 |  | Active | Preferred |  |  | Yes | Legacy Inventory Status: Cleared
 |  |  |  |  |  |  |  |  |  |  |  |  |  |  |  |  |  |  |  |  |  |  |  |  |  | true | false | NXP SEMICONDUCTORS_RMS1 | PMEG4005AEA | VERY LOW VF MEGA SCHOTTKY BARRIER RECTIFIERS | Active | Preferred |  |  | Yes | Legacy Inventory Status: Cleared
1 | true | true | false | false | false | 0 | 10022532 | FILTER CC, 1MHZ-1GHZ, 10A, 50V | B EC130338 | 1 | Each | Production |  | FL1 |  |  |  |  |  | Part | CBRM |  | 1 |  |  | true | false | MURATA MANUFACTURING CO., LTD. | BNX002-01 | FILTER | Active | Preferred |  | ROHS EXEMPTION: 7(C)-1 | Yes - by exemption | Legacy Inventory Status: Cleared
 |  |  |  |  |  |  |  |  |  |  |  |  |  |  |  |  |  |  |  |  |  |  |  |  |  | true | false | MURATA MANUFACTURING CO., LTD. | BNX00201 | NOISE/EMI SUPPRESSION FILTER | Active | Preferred |  | ROHS EXEMPTION: 7(C)-1 | Yes - by exemption | Legacy Inventory Status: Cleared
 |  |  |  |  |  |  |  |  |  |  |  |  |  |  |  |  |  |  |  |  |  |  |  |  |  | true | false | MURATA MANUFACTURING CO., LTD. | BNX002-11 | NOISE/EMI SUPPRESSION FILTER | Active | Preferred |  |  | Yes | CLEARED
1 | true | true | false | false | false | 0 | 10022548 | RESISTOR,10K OHM.0.063W,+/-1%,0603 | C ECO-R252636 | 12 | Each | Production |  | R1,R6,R7,R9,R10,R17,R19,R21,R30,R49,R53,R56 |  |  |  |  |  | Part | CBRM |  | 1 |  |  | true | false | YAGEO_RMS1 | RC0603FR-0710KL | RES 10.0K OHM 1/10W 1% 0603 SMD | Active | Preferred |  | EXEMPTION LIST-7(C)-I,CONTAINS LEAD IN GLASS OR CERAMIC OTHER THAN DIELECTRIC CERAMIC CAPACITOR | Yes - by exemption | Rohs Compliant with exemption 7(c)-I for lead in glass. Exemption expires on 21 July 2021 for Medical devices
 |  |  |  |  |  |  |  |  |  |  |  |  |  |  |  |  |  |  |  |  |  |  |  |  |  | true | false | SAMSUNG_RMS1 | RC1608F103CS | GENERAL PURPOSE CHIP RESISTOR | Active | Preferred |  | EXEMPTION LIST-7(C)-I,CONTAINS LEAD IN GLASS OR CERAMIC OTHER THAN DIELECTRIC CERAMIC CAPACITOR | Yes - by exemption | Legacy Inventory Status: Cleared
 |  |  |  |  |  |  |  |  |  |  |  |  |  |  |  |  |  |  |  |  |  |  |  |  |  | true | false | BOURNS_RMS1 | CR0603-FX-1002ELF | CHIP RESISTOR | Active | Preferred |  | EXEMPTION LIST-7(C)-I,CONTAINS LEAD IN GLASS OR CERAMIC OTHER THAN DIELECTRIC CERAMIC CAPACITOR | Yes - by exemption | Legacy Inventory Status: Cleared
 |  |  |  |  |  |  |  |  |  |  |  |  |  |  |  |  |  |  |  |  |  |  |  |  |  | true | false | YAGEO_RMS1 | 232270461003L | RESISTOR, METAL GLAZE/THICK FILM, 0.1 W, 1 %, 100 PPM, 10000 OHM, SURFACE MOUNT, 0603 | Active | Preferred |  | BRAND: PHYCOMP; EXEMPTION LIST-7(C)-I,CONTAINS LEAD IN GLASS OR CERAMIC OTHER THAN DIELECTRIC CERAMIC CAPACITOR | Yes - by exemption | Legacy Inventory Status: Cleared
1 | true | true | false | false | false | 0 | 10022551 | RESISTOR,4.7KOHM,0.063W,+/-1% | C ECO-R252636 | 1 | Each | Production |  | R41 |  |  |  |  |  | Part | CBRM |  | 1 |  |  | true | false | YAGEO_RMS1 | RC0603FR-074K7L | RESISTOR, METAL GLAZE/THICK FILM, 0.1 W, 1 %, 100 PPM, 4700 OHM, SURFACE MOUNT, 0603 | Active | Alternate |  | EXEMPTION LIST-7(C)-I,CONTAINS LEAD IN GLASS OR CERAMIC OTHER THAN DIELECTRIC CERAMIC CAPACITOR | Yes - by exemption | 2011/65/EU compliant with 7(c)-I exemption and the exemption will expired in 21 July 2021 for medical devices.
 |  |  |  |  |  |  |  |  |  |  |  |  |  |  |  |  |  |  |  |  |  |  |  |  |  | true | false | SAMSUNG_RMS1 | RC1608F472CS | LOW TOLERANCE CHIP RESISTOR | Active | Preferred |  | EXEMPTION LIST-7(C)-I,CONTAINS LEAD IN GLASS OR CERAMIC OTHER THAN DIELECTRIC CERAMIC CAPACITOR | Yes - by exemption | Legacy Inventory Status: Cleared
 |  |  |  |  |  |  |  |  |  |  |  |  |  |  |  |  |  |  |  |  |  |  |  |  |  | true | false | SAMSUNG_RMS1 | RC1608F4701CS | LOW TOLERANCE CHIP RESISTOR | Active | Preferred |  | EXEMPTION LIST-7(C)-I,CONTAINS LEAD IN GLASS OR CERAMIC OTHER THAN DIELECTRIC CERAMIC CAPACITOR | Yes - by exemption | Legacy Inventory Status: Cleared
 |  |  |  |  |  |  |  |  |  |  |  |  |  |  |  |  |  |  |  |  |  |  |  |  |  | true | false | YAGEO_RMS1 | 232270464702L | RESISTOR, METAL GLAZE/THICK FILM, 0.1 W, 1 %, 100 PPM, 4700 OHM, SURFACE MOUNT, 0603 | Active | Preferred |  | BRAND: PHYCOMP; EXEMPTION LIST-7(C)-I,CONTAINS LEAD IN GLASS OR CERAMIC OTHER THAN DIELECTRIC CERAMIC CAPACITOR | Yes - by exemption | Legacy Inventory Status: Cleared
1 | true | true | false | false | false | 0 | 10022554 | RESISTOR, 1K OHM, 0.063W,+/-1%, 0603 | C ECO-R252636 | 13 | Each | Production |  | R33,R34,R35,R36,R37,R38,R39,R40,R42,R43,R45,R46,R47 |  |  |  |  |  | Part | CBRM |  | 1 |  |  | true | false | BOURNS_RMS1 | CR0603-FX-1001ELF | CHIP RESISTOR | Active | Preferred |  | EXEMPTION LIST-7(C)-I,CONTAINS LEAD IN GLASS OR CERAMIC OTHER THAN DIELECTRIC CERAMIC CAPACITOR | Yes - by exemption | Legacy Inventory Status: Cleared
 |  |  |  |  |  |  |  |  |  |  |  |  |  |  |  |  |  |  |  |  |  |  |  |  |  | true | false | SAMSUNG_RMS1 | RC1608F1001CS |  | Active | Alternate |  | EXEMPTION LIST-7(C)-I,CONTAINS LEAD IN GLASS OR CERAMIC OTHER THAN DIELECTRIC CERAMIC CAPACITOR | Yes - by exemption | Legacy Inventory Status: Cleared
 |  |  |  |  |  |  |  |  |  |  |  |  |  |  |  |  |  |  |  |  |  |  |  |  |  | true | false | SAMSUNG_RMS1 | RC1608F1001ES | PRECISION CHIP RESISTOR | Active | Preferred |  | EXEMPTION LIST-7(C)-I,CONTAINS LEAD IN GLASS OR CERAMIC OTHER THAN DIELECTRIC CERAMIC CAPACITOR | Yes - by exemption | Legacy Inventory Status: Cleared
 |  |  |  |  |  |  |  |  |  |  |  |  |  |  |  |  |  |  |  |  |  |  |  |  |  | true | false | YAGEO_RMS1 | RC0603FR-071KL | RESISTOR, METAL GLAZE/THICK FILM, 0.1 W, 1 %, 100 PPM, 1000 OHM, SURFACE MOUNT, 0603 | Active | Preferred |  | EXEMPTION LIST-7(C)-I,CONTAINS LEAD IN GLASS OR CERAMIC OTHER THAN DIELECTRIC CERAMIC CAPACITOR | Yes | Legacy Inventory Status: Cleared
1 | true | true | false | false | false | 0 | 10022734 | RESISTOR,47K OHM,0.063W,+/-1%,0603 | B ECO-R252636 | 1 | Each | Production |  | R55 |  |  |  |  |  | Part | CBRM |  | 1 |  |  | true | false | YAGEO_RMS1 | RC0603FR-0747KL | RESISTOR, METAL GLAZE/THICK FILM, 0.1 W, 1 %, 100 PPM, 47000 OHM, SURFACE MOUNT, 0603 | Active | Preferred |  | ROHS EXEMPT: 7(C)-1 | Yes - by exemption | Legacy Inventory Status: Cleared
 |  |  |  |  |  |  |  |  |  |  |  |  |  |  |  |  |  |  |  |  |  |  |  |  |  | true | false | YAGEO_RMS1 | 232270464703L | RESISTOR, METAL GLAZE/THICK FILM, 0.1 W, 1 %, 100 PPM, 47000 OHM, SURFACE MOUNT, 0603 | Active | Preferred |  | BRAND: PHYCOMP. ROHS EXEMPT: 7(C)-1 | Yes - by exemption | Legacy Inventory Status: Cleared
 |  |  |  |  |  |  |  |  |  |  |  |  |  |  |  |  |  |  |  |  |  |  |  |  |  | true | false | BOURNS_RMS1 | CR0603-FX-473ELF | CHIP RESISTOR | Active | Preferred |  | ROHS EXEMPT: 7(C)-1 | Yes - by exemption | Legacy Inventory Status: Cleared
1 | true | true | false | false | false | 0 | 10022891 | IC,CURRENT SHUNT MONITOR,MSOP | A ECO-R252636 | 1 | Each | Production |  | U3 |  |  |  |  |  | Part | CBRM |  | 1 |  |  | true | false | TEXAS INSTRUMENTS_RMS1 | INA170EA | CURRENT SHUNT MONITOR | Active | Preferred |  | ROHS EMEMPTION: 15 | Yes | Legacy Inventory Status: Cleared
 |  |  |  |  |  |  |  |  |  |  |  |  |  |  |  |  |  |  |  |  |  |  |  |  |  | true | false | TEXAS INSTRUMENTS_RMS1 | INA170EA/2K5 | CURRENT SHUNT MONITOR | Active | Preferred |  | TAPE & REEL, 2500, ROHS EMEMPTION: 15 | Yes | Legacy Inventory Status: Cleared
 |  |  |  |  |  |  |  |  |  |  |  |  |  |  |  |  |  |  |  |  |  |  |  |  |  | true | false | TEXAS INSTRUMENTS_RMS1 | INA170EA/250 | CURRENT SHUNT MONITOR | Active | Preferred |  | TAPE & REEL, 250, ROHS EMEMPTION: 15 | Yes | Legacy Inventory Status: Cleared
1 | true | true | false | false | false | 0 | 10022896 | IC,VOLTAGE REFERENCE,5MA,3V +/-2%,SOT23 | B ECO-R252636 | 1 | Each | Production |  | U2 |  |  |  |  |  | Part | CBRM |  | 1 |  |  | true | false | NATIONAL SEMICONDUCTOR_RMS1 | LM4120AIM5-3.0/NOPB | LOW POWER VOLTAGE REFERENCE | Active | Preferred |  |  | Yes | Legacy Inventory Status: Cleared
1 | true | true | false | false | false | 0 | 10023238 | RESISTOR, 15K OHM, 0603, +/-1% | D ECO-R252636 | 5 | Each | Production |  | R2,R12,R18,R22,R54 |  |  |  |  |  | Part | CBRM |  | 1 |  |  | true | false | ASJ | CR16153FL |  | Active | Preferred |  | ROHS EXEMPT : 7(C)1 | Yes - by exemption | Legacy Inventory Status: Cleared
 |  |  |  |  |  |  |  |  |  |  |  |  |  |  |  |  |  |  |  |  |  |  |  |  |  | true | false | VISHAY_RMS1 | CRCW060315K0FKEA | THICK FILM RECTANGULAR CHIP RESISTOR | Active | Preferred |  | ROHS EXEMPT : 7(C)1 | Yes | Legacy Inventory Status: Cleared
 |  |  |  |  |  |  |  |  |  |  |  |  |  |  |  |  |  |  |  |  |  |  |  |  |  | true | false | YAGEO_RMS1 | 232270461503L | RESISTOR, METAL GLAZE/THICK FILM, 0.1 W, 1 %, 100 PPM, 15000 OHM, SURFACE MOUNT, 0603 | Active | Preferred |  | BRAND: PHYCOMP. ROHS EXEMPT : 7(C)1 | Yes - by exemption | Legacy Inventory Status: Cleared
 |  |  |  |  |  |  |  |  |  |  |  |  |  |  |  |  |  |  |  |  |  |  |  |  |  | true | false | YAGEO_RMS1 | RC0603FR-0715KL | RESISTOR, METAL GLAZE/THICK FILM, 0.1 W, 1 %, 100 PPM, 15000 OHM, SURFACE MOUNT, 0603 | Active | Preferred |  | ROHS EXEMPT : 7(C)1 | Yes - by exemption | Legacy Inventory Status: Cleared
 |  |  |  |  |  |  |  |  |  |  |  |  |  |  |  |  |  |  |  |  |  |  |  |  |  | true | false | YAGEO_RMS1 | 232270461503 | RESISTOR, METAL GLAZE/THICK FILM, 0.1 W, 1 %, 100 PPM, 15000 OHM, SURFACE MOUNT, 0603 | Active | Preferred |  | BRAND: PHYCOMP. ROHS EXEMPT : 7(C)1 | Yes - by exemption | Legacy Inventory Status: Cleared
1 | true | true | false | false | false | 0 | 10023419 | CONNECTOR, 1 CONTACTS, TEST PROBE | A ECO-R252636 | 2 | Each | Production |  | J4,J8 |  |  |  |  |  | Part | CBRM |  | 1 |  |  | true | false | INGUN | GKS 913 305 230 A 15 02 S | TEST PROBE | Active | Preferred |  |  | Yes | Legacy Inventory Status: Cleared
1 | true | true | false | false | false | 0 | 10049136 | RESISTOR 4.7K OHM 1/4W 5% 1206 | B ECO-R252636 | 1 | Each | Production |  | R44 |  |  |  |  |  | Part | CBRM |  | 1 |  |  | true | false | VISHAY_RMS1 | CRCW12064K70JNEA | RES,4.7K, 5%, 1/4W, 1206, SMT | Active | Preferred |  | EXEMPTION LIST-7(C)-I,CONTAINS LEAD IN GLASS OR CERAMIC OTHER THAN DIELECTRIC CERAMIC CAPACITOR | Yes - by exemption | 2011/65/EU compliant with 7(c)-I exemption and the exemption will expired in 21 July 2021 for medical devices.
 |  |  |  |  |  |  |  |  |  |  |  |  |  |  |  |  |  |  |  |  |  |  |  |  |  | true | false | ASJ | CR32-472-JL |  | Active | Preferred |  | EXEMPTION LIST-7(C)-I,CONTAINS LEAD IN GLASS OR CERAMIC OTHER THAN DIELECTRIC CERAMIC CAPACITOR | Yes - by exemption | Legacy Inventory Status: Cleared
 |  |  |  |  |  |  |  |  |  |  |  |  |  |  |  |  |  |  |  |  |  |  |  |  |  | true | false | YAGEO_RMS1 | RC1206JR-074K7L | RES,4.7K, 5%, 1/4W, 1206, SMT | Active | Preferred |  | EXEMPTION LIST-7(C)-I,CONTAINS LEAD IN GLASS OR CERAMIC OTHER THAN DIELECTRIC CERAMIC CAPACITOR | Yes - by exemption | 2011/65/EU compliant with 7(c)-I exemption and the exemption will expired in 21 July 2021 for medical devices.
1 | true | true | false | false | false | 0 | 10060347 | DIODE TRANSIL 33V, SMA | A ECO-R252636 | 4 | Each | Production |  | D1,D7,D9,D14 |  |  |  |  |  | Part | CBRM |  | 1 |  |  | true | false | ST MICROELECTRONICS_RMS1 | SMA6J28A-TR | HIGH JUNCTION TEMPERATURE TRANSIL | Active | Preferred |  | EXEMPTION LIST-7A. LEAD IN HIGH MELTING TEMPERATURE TYPE SOLDERS (I.E. LEAD BASED SOLDER ALLOYS CONTAINING 85% BY WEIGHT OR MORE LEAD). | Yes - by exemption | Legacy Inventory Status: Cleared
1 | true | true | false | false | false | 0 | 10060350 | CONNECTOR, ZH, 5 CIRCUITS, 1.5 MM | A ECO-R252636 | 1 | Each | Production |  | J13 |  |  |  |  |  | Part | CBRM |  | 1 |  |  | true | false | J.S.T. CORPORATION | S5B-ZR-SM4A-TF | ZH CONNECTOR | Active | Preferred |  |  | Yes | Legacy Inventory Status: Cleared
1 | true | true | false | false | false | 0 | 10060356 | TRANSISTOR MOS P CHANNEL, 60V, 1.6A, SOT23 | A ECO-R252636 | 1 | Each | Production |  | T3 |  |  |  |  |  | Part | CBRM |  | 1 |  |  | true | false | VISHAY_RMS1 | SI2309CDS-T1-GE3 | P-CHANNEL 60-V (D-S) MOSFET | Active | Preferred |  |  | Yes | Legacy Inventory Status: Cleared
1 | true | true | true | false | false | 0 | 10095972 | TRANSISTOR MOSFET, 60V, 50A, P CHANNEL | A ECO-R255176 | 5 | Each | Production |  | T2,T4,T8,T9,T14 |  |  |  |  |  | Part | CBRM |  | 1 |  |  | true | false | VISHAY_RMS1 | SUD50P06-15L-E3 |  | Active | Preferred |  | ROHS | Yes - by exemption | RoHS exemption 7a
1 | true | false | false | false | false | 0 | 10105965 | SCHEMATIC DIAGRAM, POWERPACK2 BOARD, PB500 | B ECO-R256396 | 1 |  | Production |  |  |  |  |  |  |  | Document | CBRM |  | 1
1 | true | true | false | false | false | 0 | 10106054 | FAB, PCB, POWERPACK2 BARE BOARD | A MC002637 | 1 | Each | Production |  |  |  |  |  |  |  | Part | CBRM |  | 1 |  |  | true | false | TTM | 10106054 |  | Active | Preferred |  |  | Yes | Legacy Inventory Status: Cleared
1 | true | true | false | false | false | 0 | 10107885 | CAP CER 1UF 50V X5R 10% 1210 | A ECO-R252636 | 1 | Each | Production |  | C3 |  |  |  |  |  | Part | CBRM |  | 1 |  |  | true | false | KEMET_RMS1 | C1210C105K5PAC |  | Active | Preferred |  |  | Yes | Legacy Inventory Status: Cleared
1 | true | true | false | false | false | 0 | 10107886 | CAP EL 100UF 20% 50V LOW ESR | A ECO-R252636 | 2 | Each | Production |  | C8,C9 |  |  |  |  |  | Part | CBRM |  | 1 |  |  | true | false | KEMET_RMS1 | ESW107M050AG3AA |  | Active | Preferred |  |  | Yes | Legacy Inventory Status: Cleared
1 | true | true | false | false | false | 0 | 10107888 | DIODE SCHOTTKY DUAL 70V 100MA SOT-23 | A ECO-R252636 | 1 | Each | Production |  | D5 |  |  |  |  |  | Part | CBRM |  | 1 |  |  | true | false | VISHAY_RMS1 | BAS70-05-E3-08 |  | Active | Preferred |  |  | Yes | Legacy Inventory Status: Cleared
1 | true | true | false | false | false | 0 | 10107889 | PTC RESETTABLE 33V 1.1A 2016 SMD | A ECO-R252636 | 1 | Each | Production |  | F1 |  |  |  |  |  | Part | CBRM |  | 1 |  |  | true | false | LITTELFUSE, INC. | 2016L100/33 |  | Active | Preferred |  |  | Yes | Legacy Inventory Status: Cleared
1 | true | true | false | false | false | 0 | 10107890 | HEADER 2 PIN FRICTION LOCK MOLEX KK 156 SERIES | A ECO-R252636 | 1 | Each | Production |  | J9 |  |  |  |  |  | Part | CBRM |  | 1 |  |  | true | false | MOLEX_RMS1 | 26-61-4020 |  | Active | Preferred |  |  | Yes | Legacy Inventory Status: Cleared
1 | true | true | false | false | false | 0 | 10107891 | CONNECTOR, ZH, 2 CIRCUITS, 1.5 MM | A ECO-R252636 | 1 | Each | Production |  | J10 |  |  |  |  |  | Part | CBRM |  | 1 |  |  | true | false | JST_RMS1 | S2B-ZR-SM4A-TF(LF)(SN) |  | Active | Preferred |  |  | Yes | Legacy Inventory Status: Cleared
1 | true | true | false | false | false | 0 | 10107892 | HEADER TH MOLEX MICRO-FIT 2 CIRCUITS 3MM 5A 250V | A ECO-R252636 | 1 | Each | Production |  | J11 |  |  |  |  |  | Part | CBRM |  | 1 |  |  | true | false | MOLEX_RMS1 | 43650-0229 |  | Active | Preferred |  |  | Yes | Legacy Inventory Status: Cleared
1 | true | true | false | false | false | 0 | 10107894 | CONNECTOR ZIF, 19 CONTACTS, 1 MM | A ECO-R252636 | 1 | Each | Production |  | J12 |  |  |  |  |  | Part | CBRM |  | 1 |  |  | true | false | MOLEX_RMS1 | 52207-1960 |  | Active | Alternate |  |  | Yes | Legacy Inventory Status: Cleared
 |  |  |  |  |  |  |  |  |  |  |  |  |  |  |  |  |  |  |  |  |  |  |  |  |  | true | false | MOLEX_RMS1 | 52207-1985 |  | Active | Preferred |  |  | Yes | Legacy Inventory Status: Cleared
1 | true | true | false | false | false | 0 | 10107895 | RESISTOR 470 OHM 1/8W 5% 1206 | A ECO-R252636 | 1 | Each | Production |  | R32 |  |  |  |  |  | Part | CBRM |  | 1 |  |  | true | false | YAGEO_RMS1 | RC1206JR-07470RL |  | Active | Preferred |  | ROHS EXEMPTION - 7( C )-1 ELECTRICAL AND ELECTRONIC COMPONENTS CONTAINING LEAD IN A GLASS. | Yes | Legacy Inventory Status: Cleared
 |  |  |  |  |  |  |  |  |  |  |  |  |  |  |  |  |  |  |  |  |  |  |  |  |  | true | false | VISHAY_RMS1 | CRCW1206470RJKEA |  | Active | Preferred |  | ROHS EXEMPTION - 7( C )-1 ELECTRICAL AND ELECTRONIC COMPONENTS CONTAINING LEAD IN A GLASS. | Yes | Legacy Inventory Status: Cleared
1 | true | true | false | false | false | 0 | 10107900 | IC LINEAR ACTIVE THERMISTOR MCP9700 TO-92 | A ECO-R252636 | 1 | Each | Production |  | U6 |  |  |  |  |  | Part | CBRM |  | 1 |  |  | true | false | MICROCHIP | MCP9700AT-E/TO |  | Active | Alternate |  |  | Yes | Legacy Inventory Status: Cleared
 |  |  |  |  |  |  |  |  |  |  |  |  |  |  |  |  |  |  |  |  |  |  |  |  |  | true | false | MICROCHIP | MCP9700A-E/TO |  | Active | Preferred |  |  | Yes | Legacy Inventory Status: Cleared
1 | true | true | false | false | false | 0 | 10113299 | RESISTOR 18 KOHM 0.063W +/-1% 0603 | A ECO-R252636 | 2 | Each | Production |  | R5,R15 |  |  |  |  |  | Part | CBRM |  | 1 |  |  | true | false | YAGEO_RMS1 | RC0603FR-0718KL |  | Active | Preferred |  | ROHS EXEMPTION - 7( C )-1 ELECTRICAL AND ELECTRONIC COMPONENTS CONTAINING LEAD IN A GLASS. | Yes - by exemption | Legacy Inventory Status: Cleared
1 | true | true | false | false | false | 0 | 10113300 | RESISTOR 22 KOHM 0.063W +/-1% 0603 | A ECO-R252636 | 6 | Each | Production |  | R8,R13,R20,R23,R31,R52 |  |  |  |  |  | Part | CBRM |  | 1 |  |  | true | false | YAGEO_RMS1 | RC0603JR-0722KL |  | Active | Preferred |  | ROHS EXEMPTION - 7( C )-1 ELECTRICAL AND ELECTRONIC COMPONENTS CONTAINING LEAD IN A GLASS. | Yes - by exemption | Legacy Inventory Status: Cleared
1 | true | true | false | false | false | 0 | 10113301 | RESISTOR 62 KOHM 0.063W +/-1% 0603 | A ECO-R252636 | 1 | Each | Production |  | R48 |  |  |  |  |  | Part | CBRM |  | 1 |  |  | true | false | YAGEO_RMS1 | RC0603FR-0762KL |  | Active | Preferred |  | ROHS EXEMPTION - 7( C )-1 ELECTRICAL AND ELECTRONIC COMPONENTS CONTAINING LEAD IN A GLASS. | Yes - by exemption | Legacy Inventory Status: Cleared
1 | true | true | false | false | false | 0 | 10113304 | IC REG LINEAR 5V/3.3V 350MA D2PAK-7 | A ECO-R252636 | 1 | Each | Production |  | U1 |  |  |  |  |  | Part | CBRM |  | 1 |  |  | true | false | ON SEMICONDUCTOR_RMS1 | NCV87725D7S50R4G |  | Active | Preferred |  |  | Yes | Legacy Inventory Status: Cleared
1 | true | true | false | false | false | 0 | 10126894 | MICROCONTROLLER PROGRAMMED - POWERPACK2 | A ECO-R252636 | 1 | Each | Production |  | U4 |  |  |  |  |  | Part | CBRM |  | 1 |  |  | true | false | MICROCHIP | 10126894 |  | Active | Preferred |  |  | Yes | Legacy Inventory Status: Cleared
1 | true | true | false | false | false | 0 | 10126895 | RESISTOR 68 OHM 1/4W 5% 1206 | A ECO-R252636 | 1 | Each | Production |  | R26 |  |  |  |  |  | Part | CBRM |  | 1 |  |  | true | false | VISHAY_RMS1 | CRCW120668RJKEA |  | Active | Preferred |  | ROHS EXEMPTION - 7( C )-1 ELECTRICAL AND ELECTRONIC COMPONENTS CONTAINING LEAD IN A GLASS. | Yes - by exemption | Legacy Inventory Status: Cleared
 |  |  |  |  |  |  |  |  |  |  |  |  |  |  |  |  |  |  |  |  |  |  |  |  |  | true | false | YAGEO_RMS1 | RC1206JR-0768RL |  | Active | Preferred |  | ROHS EXEMPTION - 7( C )-1 ELECTRICAL AND ELECTRONIC COMPONENTS CONTAINING LEAD IN A GLASS. | Yes - by exemption | Legacy Inventory Status: Cleared
1 | true | true | false | false | false | 0 | 312937 | RES,0OHM 1/8W 5% 1206 | C ECO-R252636 | 1 | Each | Production |  | R25 |  |  |  |  |  | Part | CBRM |  | 1 |  |  | true | false | PANASONIC (017670) | ERJ8GEY0R00V |  | Active | Preferred |  |  | RoHS3 Compliant with exemptions | RoHS3 Compliant with exemptions
1 | true | true | true | false | false | 0 | 3838600 | PC BOARD TRACABILITY LABEL | C ECO-R252633 | 1 | Each | Production |  |  |  |  |  |  |  | Part | CBRM |  | 1 |  |  | true | false | BRADY_RMS1 | 3838600-H | B-727 LABEL, POLYIMIDE, GLOSSY WHITE THERMAL TRANSFER PRINTABLE LABEL STOCK | Active | Preferred |  | CUSTOM LABEL PER COVIDIEN DRAWING 3838600 | Yes | Legacy Inventory Status: Cleared
1 | true | true | false | false | false | 0 | GR101899 | TVS AVAL DIODE ARRAY 2CH SC70-3 | A ECO-R253300 | 2 | Each | Production |  | D2,D8 |  |  |  |  |  | Part | CBRM |  | 1 |  |  | true | false | LITTLEFUSE | SP0502BAJTG |  | Active | Preferred |  |  | Yes | Legacy Inventory Status: Cleared
1 | true | true | false | false | false | 0 | GR102887 | MOSFET N-CH 30V SOT-23 | A MC007004 | 2 | Each | Production |  | T5,T11 |  |  |  |  |  | Part | CBRM |  | 1 |  |  | true | false | VISHAY_RMS1 | SI2300DS-T1-GE3 | MOSFET N-CH 30V SOT-23 | Active | Preferred |  |  | RoHS3 Compliant | Cleared
Manufacturers
Attachments(Image) | Manufacture Part Has Redline | Mfr. Name | Mfr. Part Number | Mfr. Part Description | Mfr. Part Lifecycle Phase | Preferred Status | Sites | Reference Notes | RoHS Compliant? | RoHS Compliance Statement
true | false | JABIL CIRCUIT_RMS1 | 10106052 |  | Active | Preferred |  |  | Yes | Legacy Inventory Status: Cleared
Attachments
Is Checked Out | Has Been Redlined | Filename | File Description | File Size | File Type | Attachment Type | Modified Date | Last View Date | Checkout User | Checkout Date | Checkout Location | Checkin User | Folder Number | Folder Version
false | false | 10106052C00.PDF | Approved Rev C, pdf | 107904 | PDF |  | 17/Jun/2015 10:18:43 AM BST | 17/Jun/2015 10:18:43 AM BST |  |  |  | Migration, Data | FF0007774796 | 1
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

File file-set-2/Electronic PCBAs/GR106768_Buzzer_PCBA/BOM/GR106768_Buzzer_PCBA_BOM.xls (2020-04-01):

Creator | Jenaro | Julio
Type
Description
Title Block
Item Number | Description | Subclass | Lifecycle Phase | Rev | Rev Incorp Date | Rev Release Date | Effectivity Date
GR106768 | BUZZER PCBA | Part | Production | B ECO-R252636 | 18/Nov/2014 02:51:26 PM GMT | 06/Jan/2015 05:10:58 PM GMT
Page Two
UOM | Additional Categories Part | Alternate Part(s) | Alternate FG Part(s) | Restricted Access | Vendor User Group | Data Classification | Attachment Destination | Created By | Create Date | Legacy Data Source | Divesture Destination
Each | PART CATEGORY|Pc Board |  |  |  | V - Jabil SH | Confidential |  | Schilling, Sheila | 13/Feb/2014 03:51:56 PM GMT | Agile RMS
Page Three
Product Family(s) | Item Type | Lot Serial Control | Document Number | RoHS Compliant | Bio Approval Number | Integration Description | Project(s) | Notes | Handling/Storage | Legacy Number
 | Customized | None | NODOCUMENT | Unknown |  | BUZZER PCBA | RSP - PB560-520 | Product Family : RSP - VENTILATOR SYSTEMS, Commodity Code: BPCS Add-Updt : FC02.17, Country of Origin: BPCS Add : FR = FRANCE, Shelf Life Days:BPCS Add-Updt : 0, Must Single Issue: BPCS Add : NO, Item Class: BPCS Add-Updt : GL-66 PB500 Series Ventilators/Gen 1
BOM
Level | Attachments (Image) | Manufacturer (Image) | Pending Changes (Image) | Has Been Redlined (Image) | Has Quality(Image) | Bubble Number | Item Number | Item Description | Item Rev | Qty | UOM | Item Lifecycle Phase | BOM Notes | Ref Des | Component Effective From | Component Discontinue Date | Alternate Part(s) | Alternate FG Part(s) | Alternate Document(s) | Subclass | Sites | Planned? | Scrap Factor | OP # | Thumbnail | Attachments(Image) | Manufacture Part Has Redline | Mfr. Name | Mfr. Part Number | Mfr. Part Description | Mfr. Part Lifecycle Phase | Preferred Status | Sites | Reference Notes | RoHS Compliant? | RoHS Compliance Statement
1 | true | true | false | false | false | 0 | 10021385 | RESISTOR,4.7 KOHM,+/-1%.0.063W,0402 | A ECO-R252636 | 1 | Each | Production |  | R40 |  |  |  |  |  | Part | BDRM |  | 1 |  |  | true | false | PHYCOMP_RMS1 | 232270674702L | GENERAL PURPOSE CHIP RESISTOR | Active | Preferred |  | ROHS EXEMPT: 7(C)-1 | Yes - by exemption | Legacy Inventory Status: Cleared
 |  |  |  |  |  |  |  |  |  |  |  |  |  |  |  |  |  |  |  |  |  |  |  |  |  | true | false | VISHAY_RMS1 | CRCW04024K70FKED | RESISTOR THICK FILM 4k7 1% 0.0625W 0402 VISHAY | Active | Preferred |  | ROHS EXEMPT: 7(C)-1 | RoHS3 Compliant with exemptions | Cleared 7(c)-I exemption
 |  |  |  |  |  |  |  |  |  |  |  |  |  |  |  |  |  |  |  |  |  |  |  |  |  | true | false | YAGEO/PHYCOMP_RMS1 | RC0402FR-074K7L | GENERAL PURPOSE CHIP RESISTOR | Active | Preferred |  | ROHS EXEMPT: 7(C)-1 | Yes - by exemption | Legacy Inventory Status: Cleared
1 | true | true | false | false | false | 0 | 10021387 | RESISTOR, 220 OHM,+/-1%, 0.063W, 0402 | B ECO-R252636 | 1 | Each | Production |  | R37 |  |  |  |  |  | Part | BDRM |  | 1 |  |  | true | false | YAGEO_RMS1 | 232270672201L | RESISTOR, METAL GLAZE/THICK FILM, 0.0625 W, 1 %, 100 PPM, 220 OHM, SURFACE MOUNT, 0402 | Active | Preferred |  | BRAND: PHYCOMP.ROHS EXEMPTION: 7(C)-1 | Yes - by exemption | Legacy Inventory Status: Cleared
 |  |  |  |  |  |  |  |  |  |  |  |  |  |  |  |  |  |  |  |  |  |  |  |  |  | true | false | VISHAY_RMS1 | CRCW0402220RFKED | THICK FILM, RECTANGULAR CHIP RESISTORS | Active | Preferred |  | ROHS EXEMPTION: 7(C)-1 | Yes - by exemption | Legacy Inventory Status: Cleared
 |  |  |  |  |  |  |  |  |  |  |  |  |  |  |  |  |  |  |  |  |  |  |  |  |  | true | false | YAGEO_RMS1 | RC0402FR-07220RL | RESISTOR, METAL GLAZE/THICK FILM, 0.1 W, 1 %, 100 PPM, 220 OHM, SURFACE MOUNT, 0402 | Active | Preferred |  | ROHS EXEMPTION: 7(C)-1 | Yes - by exemption | 2011/65/EU compliant with 7(c)-I exemption and the exemption will expired in 21 July 2021 for medical devices.
1 | true | true | false | false | false | 0 | 10021388 | RESISTOR, 180 KOHM, +/-1%, 0.063W.0402 | B ECO-R252636 | 1 | Each | Production |  | R41 |  |  |  |  |  | Part | BDRM |  | 1 |  |  | true | false | YAGEO_RMS1 | 232270671804L | RESISTOR, METAL GLAZE/THICK FILM, 0.0625 W, 1 %, 100 PPM, 180000 OHM, SURFACE MOUNT, 0402 | Active | Preferred |  | BRAND:PHYCOMP.ROHS EXEMPT:7(C)-1 | Yes - by exemption | Legacy Inventory Status: Cleared
 |  |  |  |  |  |  |  |  |  |  |  |  |  |  |  |  |  |  |  |  |  |  |  |  |  | true | false | VISHAY_RMS1 | CRCW0402180KFKED | THICK FILM RECTANGULAR CHIP RESISTORS | Active | Preferred |  | ROHS EXEMPT:7(C)-1 | Yes - by exemption | Legacy Inventory Status: Cleared
 |  |  |  |  |  |  |  |  |  |  |  |  |  |  |  |  |  |  |  |  |  |  |  |  |  | true | false | YAGEO_RMS1 | RC0402FR-07180KL | RESISTOR, METAL GLAZE/THICK FILM, 0.0625 W, 1 %, 100 PPM, 180000 OHM, SURFACE MOUNT, 0402 | Active | Preferred |  | ROHS EXEMPT:7(C)-1 | Yes | Legacy Inventory Status: Cleared
1 | true | true | false | false | false | 0 | 10021389 | RESISTOR, 1.5 MOHM,0.063W, 0402 | B ECO-R252636 | 1 | Each | Production |  | R43 |  |  |  |  |  | Part | BDRM |  | 1 |  |  | true | false | YAGEO_RMS1 | 232270671505L | RESISTOR, METAL GLAZE/THICK FILM, 0.0625 W, 1 %, 100 PPM, 1500000 OHM, SURFACE MOUNT, 0402 | Active | Preferred |  | BRAND: PHYCOMP.ROHS COMPLIANT: 7(C)-1 | Yes - by exemption | Legacy Inventory Status: Cleared
 |  |  |  |  |  |  |  |  |  |  |  |  |  |  |  |  |  |  |  |  |  |  |  |  |  | true | false | YAGEO_RMS1 | RC0402FR-071M5L | RESISTOR, METAL GLAZE/THICK FILM, 0.0625 W, 1 %, 100 PPM, 1500000 OHM, SURFACE MOUNT, 0402 | Active | Preferred |  | ROHS COMPLIANT: 7(C)-1 | Yes - by exemption | Legacy Inventory Status: Cleared
 |  |  |  |  |  |  |  |  |  |  |  |  |  |  |  |  |  |  |  |  |  |  |  |  |  | true | false | VISHAY_RMS1 | CRCW04021M50FKED | THICK FILM, RECTANGULAR CHIP RESISTORS | Active | Preferred |  | ROHS COMPLIANT: 7(C)-1 | Yes - by exemption | Legacy Inventory Status: Cleared
1 | true | true | false | false | false | 0 | 10021390 | CAPACITOR,4.7NF,16V,+/-10%,0402 | B ECO-R252636 | 1 | Each | Production |  | C35 |  |  |  |  |  | Part | BDRM |  | 1 |  |  | true | false | YAGEO_RMS1 | CC0402KRX7R7BB472 | CAPACITOR, CERAMIC, MULTILAYER, 16 V, X7R, 0.0047 UF, SURFACE MOUNT, 0402 | Active | Preferred |  |  | Yes | Legacy Inventory Status: Cleared
 |  |  |  |  |  |  |  |  |  |  |  |  |  |  |  |  |  |  |  |  |  |  |  |  |  | true | false | YAGEO_RMS1 | 223878715632 | CAPACITOR, CERAMIC, MULTILAYER, 16 V, X7R, 0.0047 UF, SURFACE MOUNT, 0402 | Active | Preferred |  | BRAND: PHYCOMP | Yes | Legacy Inventory Status: Cleared
1 | true | true | false | false | false | 0 | 10021391 | RESISTOR, 680 KOHM,+/-1%, 0.063W, 0402 | B ECO-R252636 | 1 | Each | Production |  | R44 |  |  |  |  |  | Part | BDRM |  | 1 |  |  | true | false | YAGEO_RMS1 | RC0402FR-07680KL | RESISTOR, METAL GLAZE/THICK FILM, 0.0625 W, 1 %, 100 PPM, 680000 OHM, SURFACE MOUNT, 0402 | Active | Preferred |  | ROHS EXEMPT: 7(C)-1 | Yes - by exemption | Legacy Inventory Status: Cleared
 |  |  |  |  |  |  |  |  |  |  |  |  |  |  |  |  |  |  |  |  |  |  |  |  |  | true | false | YAGEO_RMS1 | 232270676804L | RESISTOR, METAL GLAZE/THICK FILM, 0.0625 W, 1 %, 100 PPM, 680000 OHM, SURFACE MOUNT, 0402 | Active | Preferred |  | BRAND: PHYCOMP.ROHS EXEMPT: 7(C)-1 | Yes - by exemption | Legacy Inventory Status: Cleared
 |  |  |  |  |  |  |  |  |  |  |  |  |  |  |  |  |  |  |  |  |  |  |  |  |  | true | false | VISHAY_RMS1 | CRCW0402680KFKED | THICK FILM, RECTANGULAR CHIP RESISTORS | Active | Preferred |  | ROHS EXEMPT: 7(C)-1 | Yes - by exemption | Legacy Inventory Status: Cleared
1 | true | true | false | false | false | 0 | 10021462 | RESISTOR, 1 MOHM, +/-1%,0.063W,0402 | B ECO-R252636 | 1 | Each | Production |  | R46 |  |  |  |  |  | Part | BDRM |  | 1 |  |  | true | false | YAGEO_RMS1 | 232270671005L | RESISTOR, METAL GLAZE/THICK FILM, 0.0625 W, 1 %, 100 PPM, 1000000 OHM, SURFACE MOUNT, 0402 | Active | Preferred |  | BRAND: PHYCOMP.ROHS EXMEPT: 7(C)-1 | Yes - by exemption | Legacy Inventory Status: Cleared
 |  |  |  |  |  |  |  |  |  |  |  |  |  |  |  |  |  |  |  |  |  |  |  |  |  | true | false | YAGEO_RMS1 | RC0402FR-071ML | RESISTOR, METAL GLAZE/THICK FILM, 0.0625 W, 1 %, 100 PPM, 1000000 OHM, SURFACE MOUNT, 0402 | Active | Preferred |  | ROHS EXMEPT: 7(C)-1 | RoHS3 Compliant with exemptions | Exemption 7(c)-I shown on RoHS evidence
 |  |  |  |  |  |  |  |  |  |  |  |  |  |  |  |  |  |  |  |  |  |  |  |  |  | true | false | VISHAY_RMS1 | CRCW04021M00FKED | RESISTOR 1M 1% 0.0625W 0402 VISHAY | Active | Preferred |  | ROHS EXMEPT: 7(C)-1 | RoHS3 Compliant with exemptions | Cleared. Exemption 7(c)-I
1 | true | true | false | false | false | 0 | 10021463 | CAPACITOR,47UF,16V,1210,X5R | C ECO-R252636 | 2 | Each | Production |  | C21,C23 |  |  |  |  |  | Part | BDRM |  | 1 |  |  | true | false | KEMET_RMS1 | C1210C476M4PACTU |  | Active | Preferred |  |  | Yes | Legacy Inventory Status: Cleared
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

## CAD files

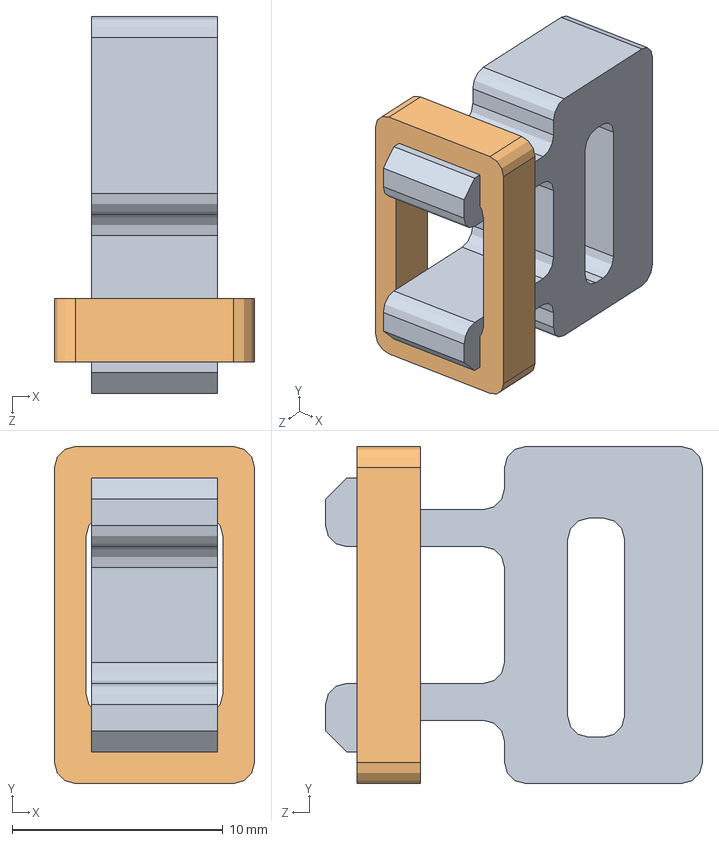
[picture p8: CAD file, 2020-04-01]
file-set-2/Mechanical Part Drawings/3822900/serre cable 03 japon.SLDASM
9.50 x 16.0 x 17.9 mm
Pince 1-03 serre cable japon
Pince 2-03 serre cable japon

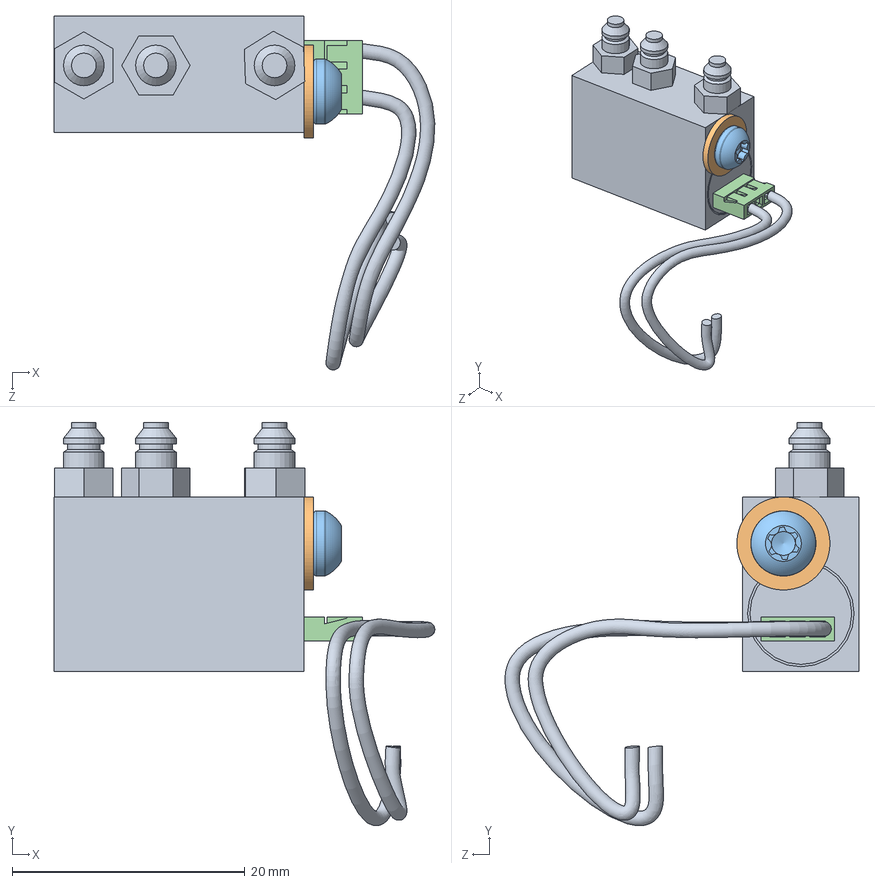
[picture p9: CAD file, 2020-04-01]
file-set-2/Electronic PCBAs/GR106769_CPU_PCBA/3D_Model/valve chiprop.SLDASM
32.7 x 34.7 x 30.4 mm
valve chiprop
2004200 Rondelle plate - MN INOX 3 x 8 EP 0.8
2966100 Vis TCB M3 x 5 exalobes acier zingué
connector

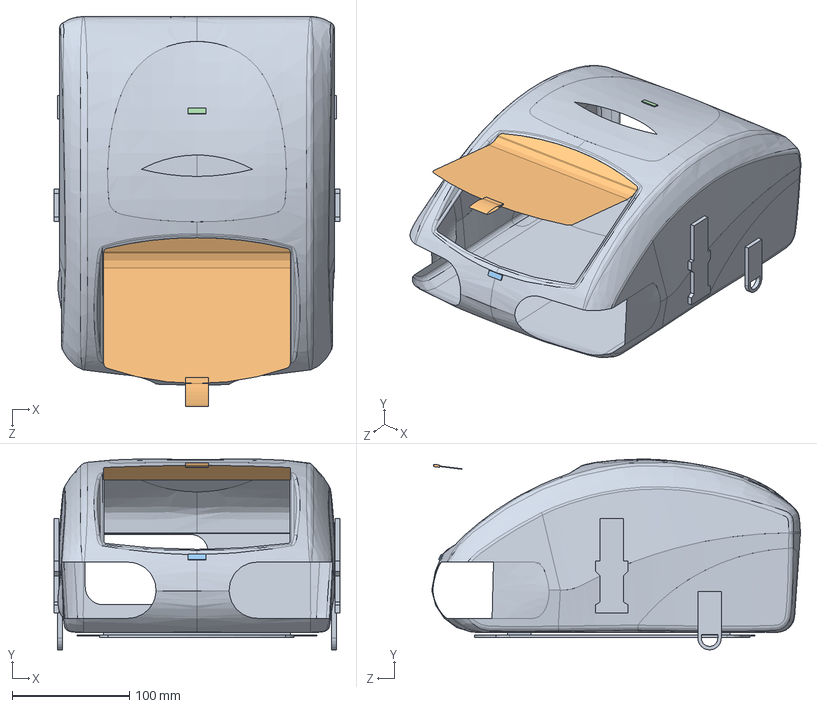
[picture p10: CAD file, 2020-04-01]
file-set-2/Mechanical Part Drawings/2967200/sacoche sacar.SLDASM
244.0 x 163.0 x 333.2 mm
peau exterieure
visière
scratch visière fermée
scratch visière ouverte

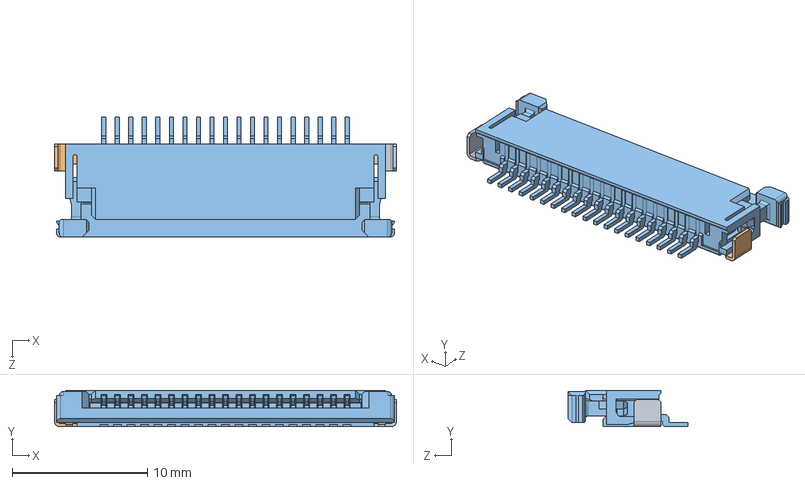
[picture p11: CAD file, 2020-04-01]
file-set-2/Electronic PCBAs/10106052_PowerPack_PCBA/PCBA/MOLEX 52207-1960.SLDASM
25.3 x 2.70 x 8.90 mm

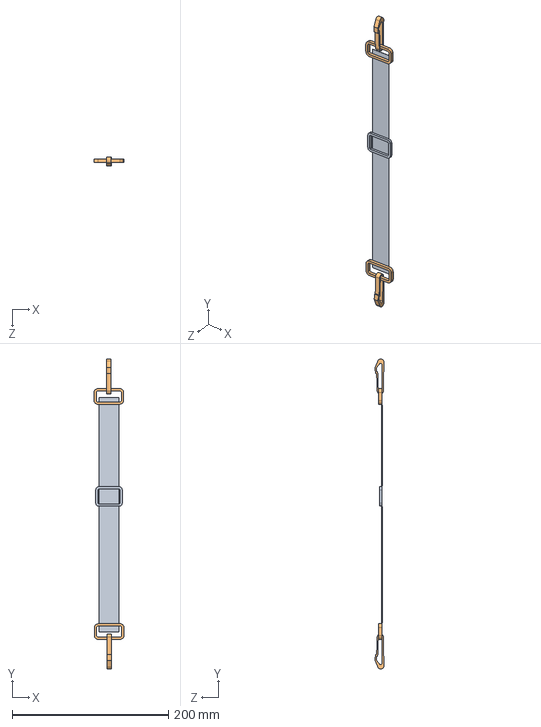
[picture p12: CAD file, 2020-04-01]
file-set-2/Mechanical Part Drawings/2967200/Assemblage suspente.SLDASM
38.4 x 396.5 x 11.3 mm
suspente
mousqueton x 2

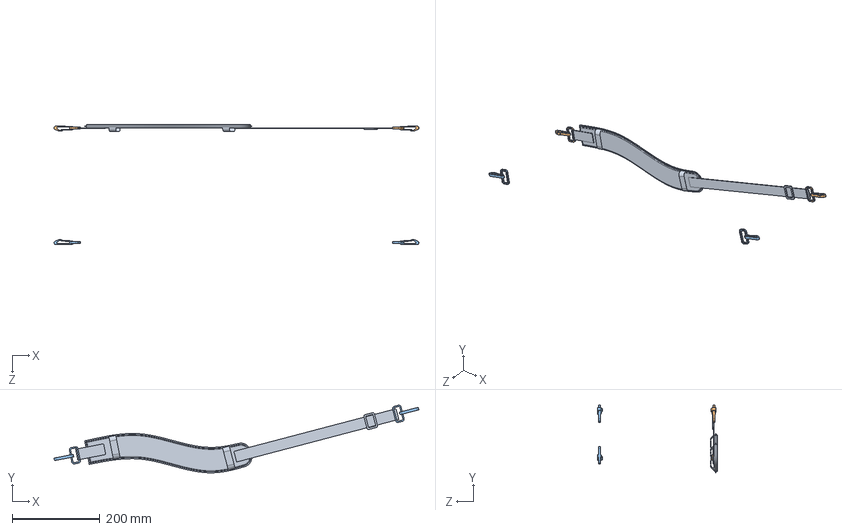
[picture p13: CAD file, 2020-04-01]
file-set-2/Mechanical Part Drawings/2967200/sangle droite.SLDASM
832.5 x 154.4 x 274.2 mm
sangle bandoulliere droite
mousqueton x 2
Symétriemousqueton x 2

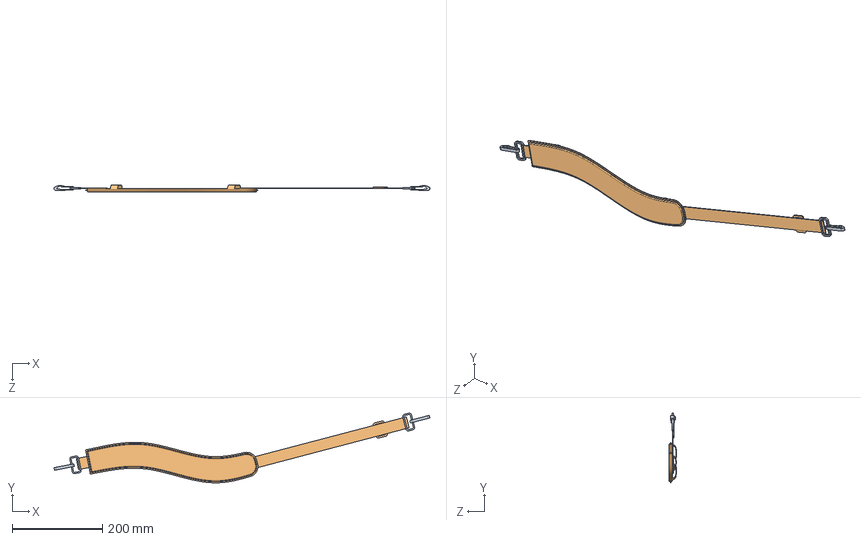
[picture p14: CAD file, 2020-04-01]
file-set-2/Mechanical Part Drawings/2967200/Assemblage3^sangle gauche.sldasm
832.5 x 154.4 x 16.2 mm
Symétriemousqueton x 2
Symétriesangle bandoulliere droite

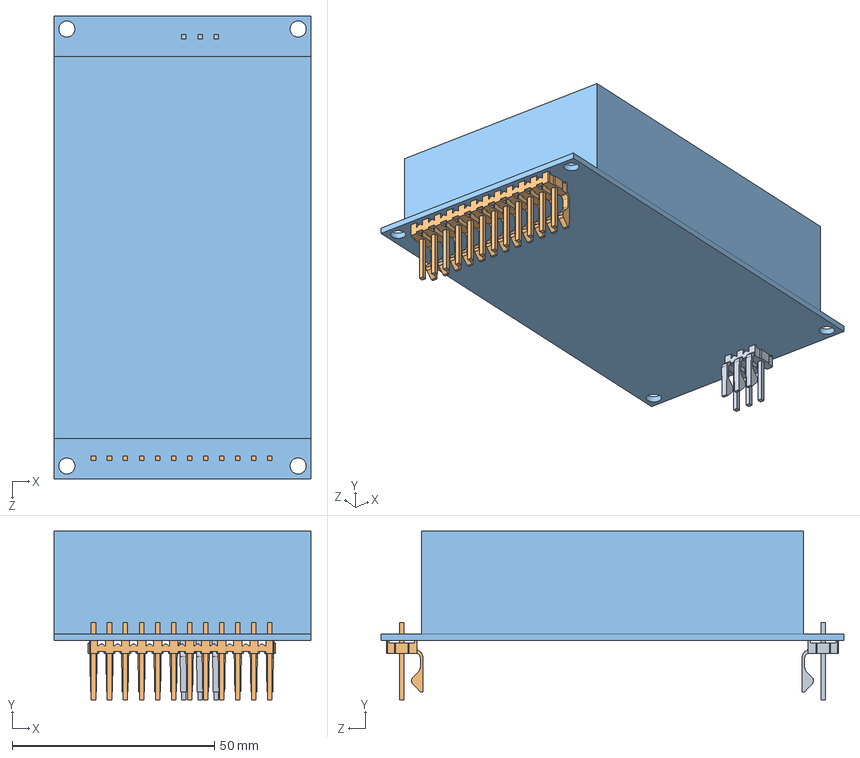
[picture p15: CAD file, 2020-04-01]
file-set-2/Electronic PCBAs/10005011_Power Management_PCBA/3842800_POWER SUPPLY BOARD - TANTALUM LESS_PCBA/PCBA/alimentation xp.sldasm
63.5 x 41.7 x 114.3 mm
alimentation phase 2

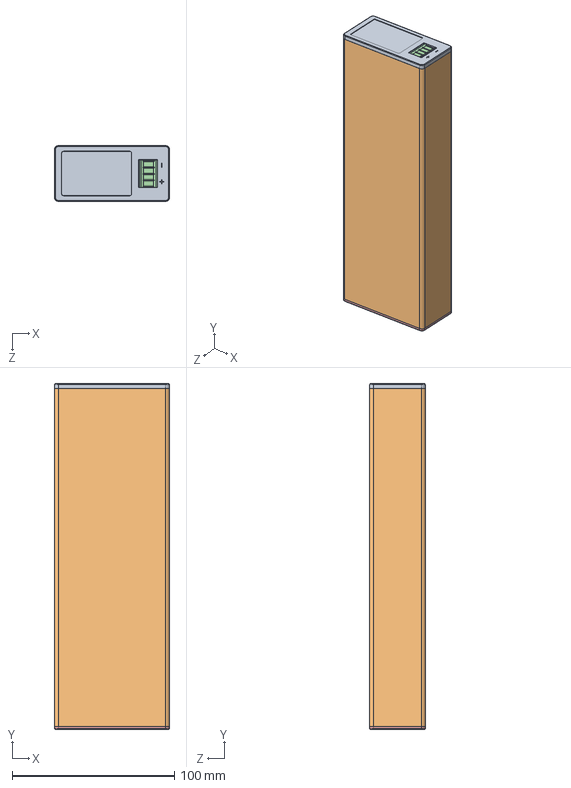
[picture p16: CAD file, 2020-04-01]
file-set-2/3D CAD Models/Batt Assy.SLDASM
71.0 x 213.0 x 34.5 mm
Front End Cap
Extruded housing
Batt PCB
Batt Contacts tab
Back End Cap

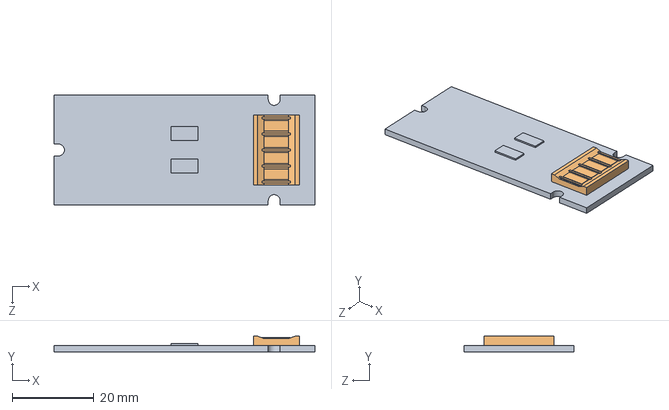
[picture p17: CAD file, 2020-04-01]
file-set-2/3D CAD Models/Batt PCB Assy.SLDASM
63.9 x 3.85 x 26.9 mm
Batt PCB
Batt Contacts tab

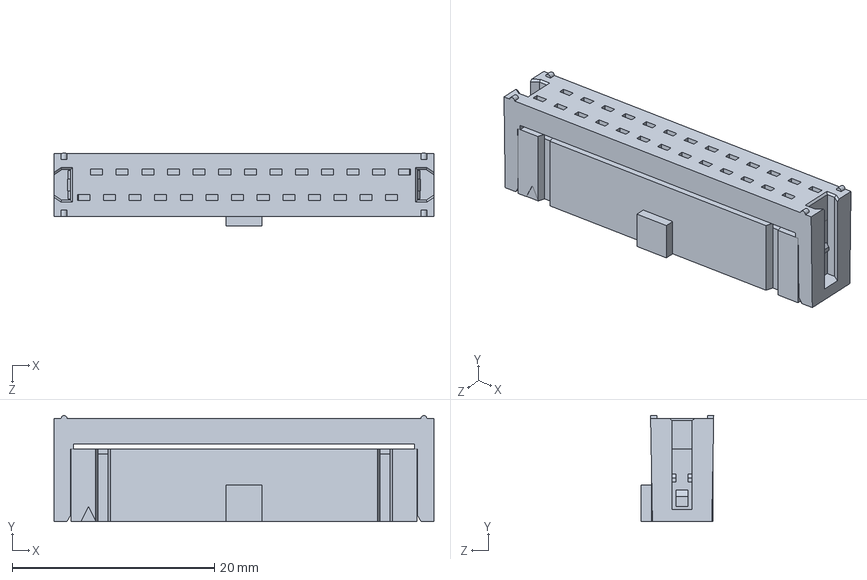
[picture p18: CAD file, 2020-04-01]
file-set-2/3D CAD Models/Molex 90635-1262.SLDPRT
37.6 x 10.5 x 7.18 mm

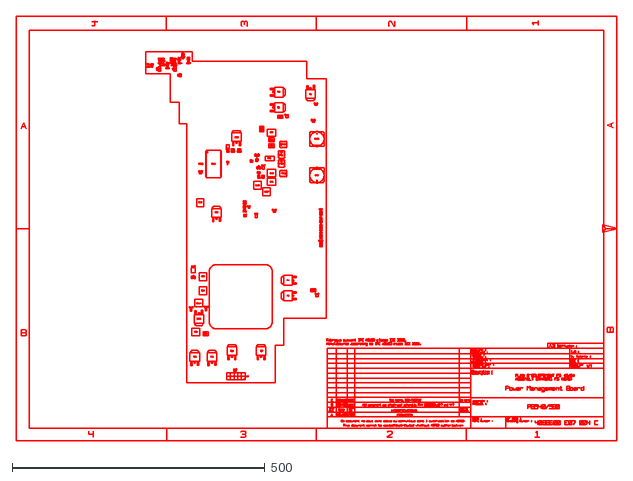
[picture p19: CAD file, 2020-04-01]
file-set-2/Electronic PCBAs/10005011_Power Management_PCBA/3842800_POWER SUPPLY BOARD - TANTALUM LESS_PCBA/PCB/Power Supply Board 3842800 (Tantalum Less) INDC/eqfs.dxf
1188.3 x 840.3

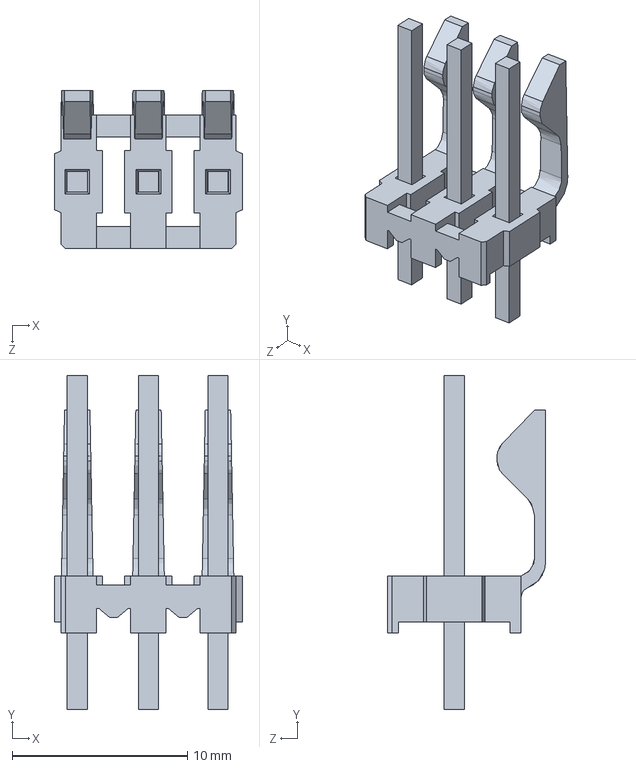
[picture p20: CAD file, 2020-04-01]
file-set-2/Electronic PCBAs/10005011_Power Management_PCBA/3842800_POWER SUPPLY BOARD - TANTALUM LESS_PCBA/PCBA/26-48-1035.SLDPRT
10.7 x 19.1 x 9.02 mm

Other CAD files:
file-set-2/Mechanical Part Drawings/3829000/Assemblage suspente.SLDASM
file-set-2/Mechanical Part Drawings/2967200/Assemblage2^sangle droite.sldasm
file-set-2/3D CAD Models/PMCD1204.sldasm
file-set-2/3D CAD Models/valve chiprop.SLDASM
file-set-2/3D CAD Models/alimentation xp.sldasm
file-set-2/3D CAD Models/039281023.SLDPRT
file-set-2/3D CAD Models/09-48-4038.SLDPRT
file-set-2/3D CAD Models/09-48-4128.SLDPRT
file-set-2/3D CAD Models/10049560_Fan Assy (ref ASM).SLDASM
file-set-2/3D CAD Models/10049560_Routed wires (asm ref Part).SLDPRT
file-set-2/3D CAD Models/10049560_ventil SUNON 40x40x20.SLDPRT
file-set-2/3D CAD Models/10079556.SLDASM
file-set-2/3D CAD Models/10079556_Support.SLDPRT
file-set-2/3D CAD Models/10093284.SLDPRT
file-set-2/3D CAD Models/10096315.SLDASM
file-set-2/3D CAD Models/10096505_Board (ref ECAD).SLDPRT
file-set-2/3D CAD Models/10096509.SLDASM
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

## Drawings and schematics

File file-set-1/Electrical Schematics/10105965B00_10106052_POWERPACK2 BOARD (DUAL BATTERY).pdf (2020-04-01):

D | D
C | C
B | B
A | A
3 | Project: Powerpack2 (dual battery)

4

# Power supply & Switching Microcontroller

# 3. Bypass capacitors shall be distributed evenly amongst power

pins of the IC power and GND pin.

# 4. Always observe layout guidelines and documentation from the component

manufacturers, beside the indications and comments marked on schematics.

R?

# SHEET

# 1. Components marked with a dashed and crossed box will not

be installed during assembly.

# Title Page

# DESCRIPTION

# TABLE OF CONTENTS

2 | Block Diagram

NOTES: UNLESS OTHERWISE SPECIFIED.

1

2. Please refer to the 10106052 - Powerpack board (dual battery) Bill of Material (BOM) which provides all necessary component information for the final assembly.

# 5. J1 to J8 conn - Through hole components, place on Top side of the PCB

# 6. RL1, FL1, J9 & J11 conn - Through hole components, place on Top right side of the PCB

# 7. J12 conn - SMD component, place on Bottom left side of the PCB

8. Power tracks - marked with thick line on schematic, should be able to withstand minimum 3.3A continuous current route as wide as possible, minimum of 0.6mm.
9. Components names to be marked in silkscreen and also PCB board name, number and revision.
Revision Changes | REVISIONS
REV | DESCRIPTION | DATE | APPROVED
B B B | RELEASE PER ECO-R249715 RELEASE PER ECO-R249715 RELEASE PER ECO-R249715 | SEE AGILE SEE AGILE SEE AGILE | SEE AGILE SEE AGILE SEE AGILE
REV | DESCRIPTION
X01 | Initial release
X02 | D16 added, U1 part number updated to TPS7A1650Q1, C13,C16,C18,C20 to be mounted by default on PCBA.
X03 | Removed D16, replaced with T14, T15, R52 to R56. Capacitors C13, C15, C16, C17, C18, C19, C20, C21 removed. R5, R15 value changed to 18k. R41 value changed to 4.7k. R48 value changed to 62k. U1 changed to NCV87725D7S50R4G. Removed RS-232 interface (U5, C26, C27, C28, C29, C31, J14). Deleted TP1 to TP10. R57, R58 added. R4, R14, R50, R51, R57, R58, D15, T12, T13 marked as not installed.
A | Production release. Changed R26 to 68 Ohm & R32 to 2.2k.
B | Changed R32 to 470 Ohm.

# ORCAD CAPTURE DRAWING -ALL CHANGES MUST BE DONE IN ORCAD SYSTEM

# ORCAD CAPTURE DRAWING -ALL CHANGES MUST BE DONE IN ORCAD SYSTEM

# ORCAD CAPTURE DRAWING -ALL CHANGES MUST BE DONE IN ORCAD SYSTEM

SIZE SIZE SIZE B B B | MODEL MODEL MODEL PB500 PB500 PB500 | DWG NO. DWG NO. DWG NO. 10105965 10105965 10105965 | REV: REV: REV: B B B

# Carlsbad, CA 92008

# 2101 Faraday Avenue

# CONFIDENTIAL STATEMENT

### Copyright (C) 2013, Covidien The information contained in this document is the

proprietary and confidential property of Covidien.

### Supplied Data, Tooling, Partial or Finished Materials shall not be disclosed to others without

the written permissions of Covidien.

APPROVALS APPROVALS APPROVALS | DATE DATE DATE
DRAWN: DRAWN: DRAWN: | 14-May-2013 14-May-2013 14-May-2013 | SCHEMATIC DIAGRAM SCHEMATIC DIAGRAM SCHEMATIC DIAGRAM POWERPACK2 BOARD, PB500 POWERPACK2 BOARD, PB500 POWERPACK2 BOARD, PB500
ENGINEER: ENGINEER: ENGINEER: | 14-May-2013 14-May-2013 14-May-2013
SEE AGILE CHECKED CHECKED CHECKED | SEE AGILE
APPROVED APPROVED APPROVED SEE AGILE SEE AGILE SEE AGILE | SEE AGILE SEE AGILE SEE AGILE
RELEASED: RELEASED: RELEASED: SEE AGILE SEE AGILE SEE AGILE | SEE AGILE SEE AGILE SEE AGILE | SCALE: NONE SCALE: NONE SCALE: NONE | Template 10093694 Rev A Template 10093694 Rev A Template 10093694 Rev A | SHEET SHEET SHEET 1 1 1 4 4 4 of of of

# Carlsbad, CA 92008

# 2101 Faraday Avenue

# CONFIDENTIAL STATEMENT

### Copyright (C) 2013, Covidien The information contained in this document is the

proprietary and confidential property of Covidien.

### Supplied Data, Tooling, Partial or Finished Materials shall not be disclosed to others without

the written permissions of Covidien.

# Carlsbad, CA 92008

# 2101 Faraday Avenue

# CONFIDENTIAL STATEMENT

### Copyright (C) 2013, Covidien The information contained in this document is the

proprietary and confidential property of Covidien.

### Supplied Data, Tooling, Partial or Finished Materials shall not be disclosed to others without

the written permissions of Covidien.

# POWERPACK2 PCBA
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
